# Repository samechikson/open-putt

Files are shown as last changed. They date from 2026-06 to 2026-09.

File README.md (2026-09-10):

# Open Putt

This repo has the code and instructions to build a 3D printed golf putting-analysis tool to measure a player's putting accuracy and speed.

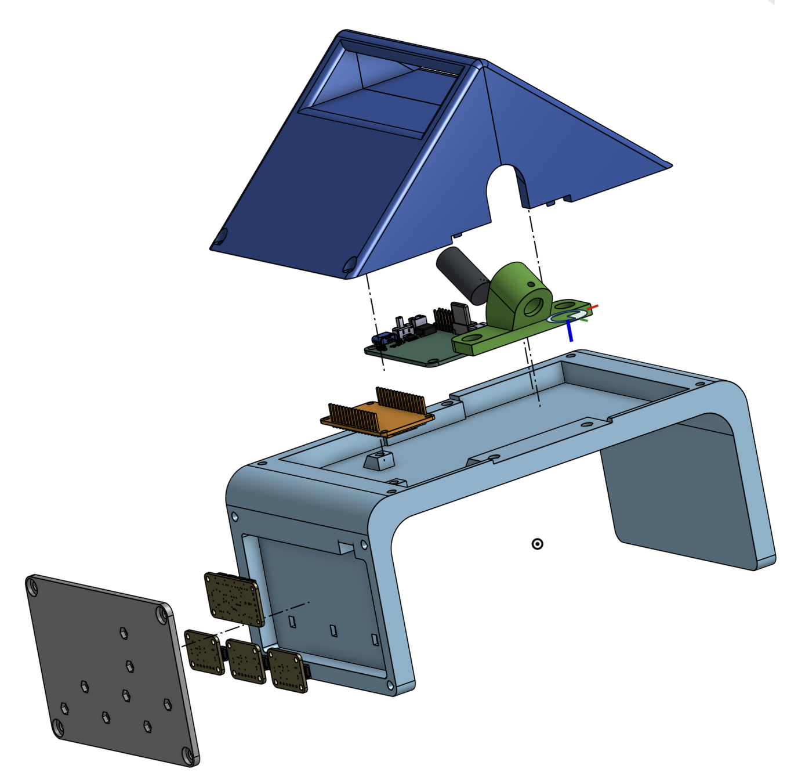
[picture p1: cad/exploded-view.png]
Exploded view of the Open Putt enclosure and components


---

## Repository layout

| Path | What it is |
|---|---|
| `microcontroller/` | ESP32 (Arduino C++) firmware for the physical laser gate + ToF sensors, and its bring-up sketches. |
| `cad/` | Renders and print settings for the 3D-printed enclosure; links to the editable CAD in Onshape. |
| `ios/` | SwiftUI app (`PuttingGate`). Connects to the hardware gate over BLE and writes each putt **directly to Firestore** via the Firebase iOS SDK; shows history/settings. |
| `frontend/` | React 19 + TypeScript + Vite + Tailwind v4 web app for showing history of putting sessions. Reads/writes Firestore **directly** via the Firebase Web SDK (no backend calls). Served by Firebase Hosting. |
| `backend/` (optional) | Python / FastAPI service on Google Cloud Run. Now only the legacy ESP32 direct-post ingest path (`POST /api/device/putts`, Admin SDK). |
| `backend/db/README.md` | The Firestore collection model (data lives in Firestore Native mode). |
| `firestore.rules` / `firestore.indexes.json` | Per-user client access for the web + iOS apps; no composite indexes. |
| `docs/` | Operator runbooks (the Firestore + Firebase-auth migration runbooks). |
| `start.sh` | One command to run the whole web stack locally (with the Firestore emulator). |

---

## Getting started

- **Build a gate and run it end-to-end** — gather parts, print the enclosure, wire
  and flash the electronics, and roll your first putt:
  [`ASSEMBLY.md`](ASSEMBLY.md).
- **Run the software on your own infrastructure** — your Firebase project, the web +
  iOS apps, and the optional backend: [`SETUP.md`](SETUP.md).

Each component has a deeper doc: [`microcontroller/README.md`](microcontroller/README.md)
(hardware wiring, geometry, firmware), [`cad/README.md`](cad/README.md) (the printable
enclosure), [`backend/db/README.md`](backend/db/README.md) (the Firestore data model),
and [`CLAUDE.md`](CLAUDE.md) (architecture and conventions).

---

## Development

### Run the whole web stack locally

```bash
./start.sh
```

Sets `AUTH_DEV_UID=local-dev` (skips Firebase verification, attributes all data to one
dev user). Creates `backend/.venv`, runs uvicorn on `:8000`
(`app.main:application --reload`), and `npm run dev` on `:5173` (Vite proxies `/api` →
`localhost:8000`).

**Local database:** `start.sh` launches the **Firestore emulator** (`localhost:8080`)
and points the backend at it via `FIRESTORE_EMULATOR_HOST`, so persistence works
without touching real Firestore. Needs the Firebase CLI (`npm i -g firebase-tools`)
and a Java runtime; without `firebase` on PATH the script warns and runs without
persistence (the app still runs, nothing persists).

### Frontend only

```bash
cd frontend
npm install
npm run dev      # Vite dev server
npm run build    # tsc -b && vite build → frontend/dist
npm run lint     # oxlint
```

Needs `frontend/.env.local` with the `VITE_FIREBASE_*` values for real auth.

### Backend only

```bash
cd backend
python3 -m venv .venv && .venv/bin/pip install -r requirements.txt
AUTH_DEV_UID=dev FIRESTORE_EMULATOR_HOST=localhost:8080 \
  .venv/bin/uvicorn app.main:application --reload --port 8000
```

There is no automated test suite yet, so **verify changes by exercising the flow** —
post a putt to `/api/device/putts` (or relay one from the gate via iOS) and confirm it
reads back from `/api/sessions/{id}/putts`.

### iOS

Open `ios/PuttingGate.xcodeproj` in Xcode, build & run. Requires the Firebase SPM
package and `GoogleService-Info.plist` in the target. To exercise the gate you need the
physical ESP32 device advertising over BLE.

### Microcontroller

From a sketch folder:

```bash
arduino-cli compile --fqbn esp32:esp32:esp32:PartitionScheme=huge_app --upload -p /dev/cu.usbserial-0001 .
arduino-cli monitor -p /dev/cu.usbserial-0001 -c baudrate=115200
```

---

## Deployment

- **Frontend** auto-deploys to Firebase Hosting on push to `main` touching
  `frontend/**`, `firebase.json`, or the workflow
  (`.github/workflows/deploy-frontend.yml`). Vite bakes the `VITE_*` env into the bundle
  at build time.
- **Firestore rules/indexes** are *not* in that workflow (hosting only). The web app
  depends on `firestore.rules`, so deploy them after any change:
  `firebase deploy --only firestore:rules,firestore:indexes`.
- **Backend** deploys to Cloud Run via `bash backend/deploy/cloud-run.sh` (provisioning;
  `--fast` for a code-only rebuild+redeploy). Container is `backend/Dockerfile`
  (Python 3.13-slim; single uvicorn worker — scale via Cloud Run instances). It also
  provisions a **Firestore Native database** and grants the runtime SA
  `roles/datastore.user`. Secrets: `CORS_ALLOW_ORIGINS`, `DEVICE_INGEST_TOKEN` /
  `DEVICE_INGEST_UID` (the legacy direct-post device auth); no DB secret — Firestore
  uses the runtime SA.

> `main` auto-deploys the frontend — be deliberate about what lands there.

---

## License

Released under the [MIT License](LICENSE).

---

For deeper guidance on conventions and cross-cutting changes, see
[`CLAUDE.md`](CLAUDE.md).

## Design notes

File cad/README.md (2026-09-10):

# CAD

**DISCLAIMER**: These files are a work in progress and may change at any time.

<table>
  <tr>
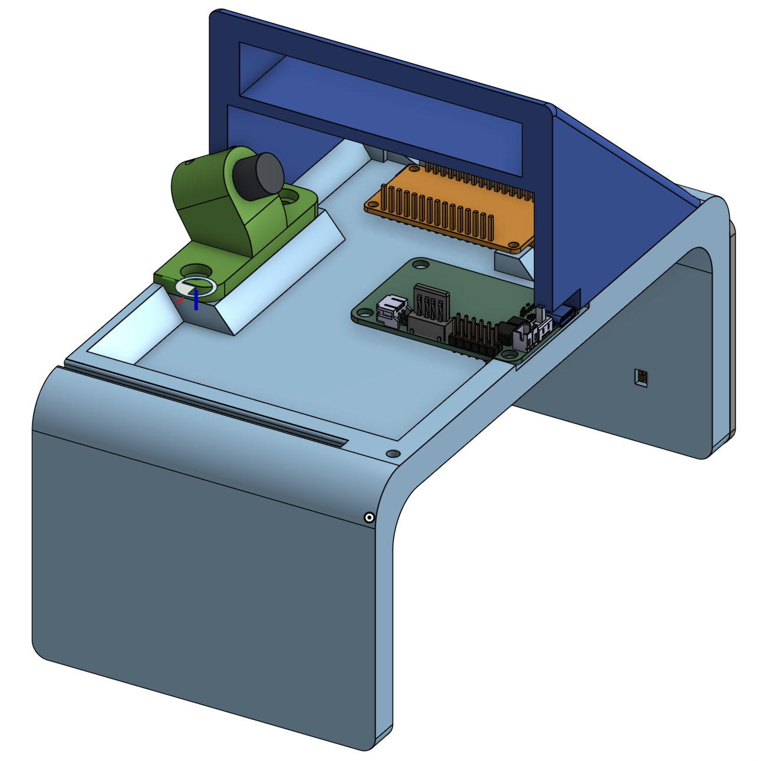
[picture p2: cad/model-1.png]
Rendered CAD model of the Open Putt enclosure
    <td></td>
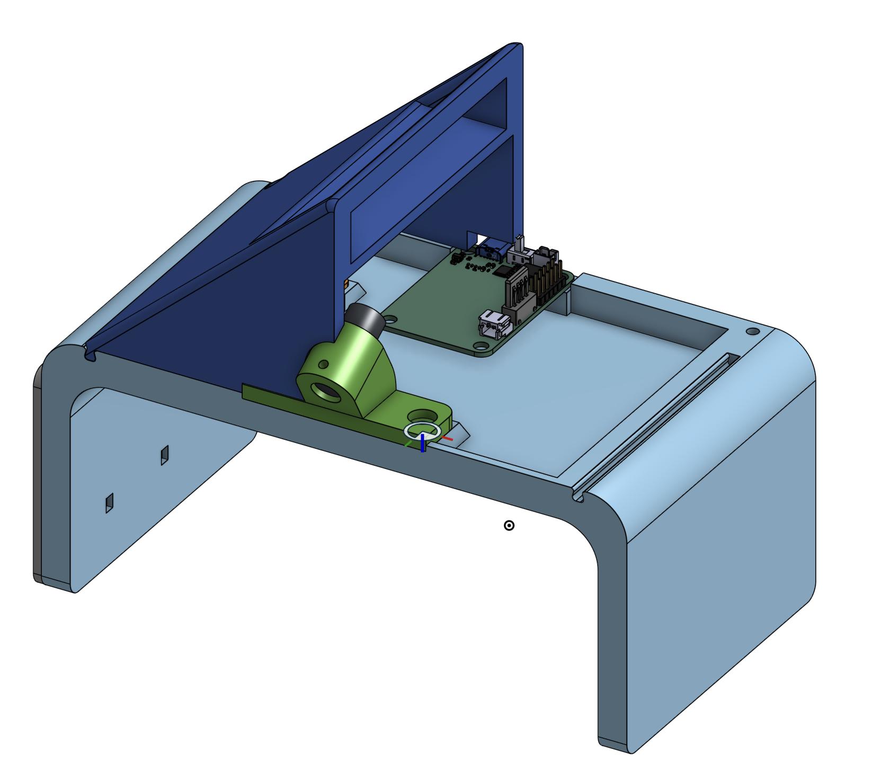
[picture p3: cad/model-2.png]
Rendered CAD model of the Open Putt enclosure
    <td></td>
    
  </tr>
  <tr>
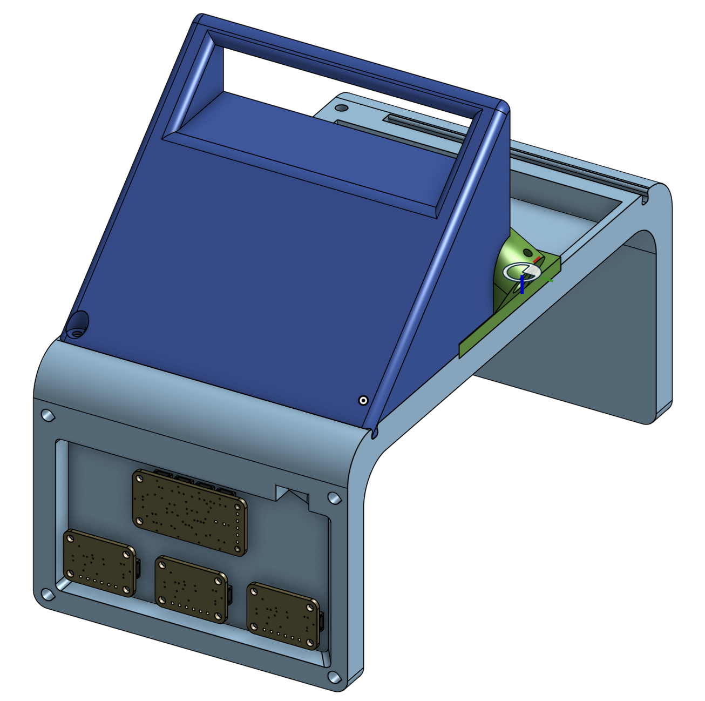
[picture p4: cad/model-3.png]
Rendered CAD model of the Open Putt enclosure
    <td></td>
    <td>Rendered CAD model of the Open Putt enclosure</td>
  </tr>
</table>

CAD for the **Open Putt** enclosure — the 3D-printed "bridge" a golf ball rolls
through. The models live in Onshape (link below); export and print the parts to
build your own gate. The electronics that mount inside are in
[`PARTS_LIST.md`](../PARTS_LIST.md), and the wiring + measurement geometry are in
[`microcontroller/README.md`](../microcontroller/README.md).

## Editable source (Onshape)

The CAD lives in a public Onshape document — open it to view, measure, or remix any
part, then export each part as STL (or STEP) to slice and print:

**<https://cad.onshape.com/documents/c4b592de0452c28abc40e1e5/w/5af483f8f7800af7bf8093f1/e/e14822a6b83e241d4da19292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>**

## Printing

From [`PARTS_LIST.md`](../PARTS_LIST.md):

- A filament 3D printer with at least a **210 × 210 × 200 mm** build volume.
- **PLA or PETG** filament (PETG if the gate will sit in sun/heat).
- **M3 and M4 heat-set threaded inserts** for the mounting bosses.

General guidance (tune per part / printer):

- ~0.2 mm layer height, 3–4 perimeters, 15–20% infill — the gate is structural,
  not cosmetic.
- Print sensor and laser mounts in the orientation that keeps their mating faces
  flat and square, so alignment holds without support scarring.
- Set your slicer's hole/insert diameters to your inserts; heat-set them after
  printing.

## Contributing

Improvements and remixes are welcome. If you change a mount that affects sensor or
laser geometry, note it in your PR so the calibration/measurement docs can be kept
honest — see [`microcontroller/README.md`](../microcontroller/README.md) for the
geometry the firmware assumes.

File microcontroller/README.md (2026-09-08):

# Putt Offline Detector

A device that a golf ball rolls through (a 3D-printed "bridge" gate) which measures
how far **offline** each putt is from the center line, reporting it as **PUSH**
(ball past center) or **PULL** (ball short of center) in millimeters. Built first on
a Raspberry Pi, then migrated to an ESP32 for portability.

---

## Current status

- ✅ **Laser** on at startup
- ✅ **3× VL53L4CD** distance sensors read through an I2C multiplexer
- ✅ **Putt detection + push/pull offset** working standalone on the ESP32 (verified:
  a real putt reported a consistent ~+43 mm PUSH across all three sensors)
- ✅ **Per-sensor speed + center calibration** (per-sensor `CENTER_READING`, jig-measured)
- ✅ **BLE to the phone** — each putt is sent over BLE to the iOS app, which relays it to
  the backend under the signed-in user (no WiFi/hotspot on the ESP32). See "Transport".

---

## Hardware

### Final build (ESP32)

| Part | Notes |
| --- | --- |
| **ELEGOO ESP32 DevKit** (ESP32-WROOM-32, USB-C, CP2102) | Classic dual-core, WiFi + BT/BLE 4.2. 2.4 GHz WiFi only. |
| **3× Adafruit VL53L4CD** ToF distance sensors (~1–1300 mm) | All share I2C address `0x29`. |
| **Adafruit PCA9548** I2C multiplexer (TCA9548A-compatible) | Address `0x70`. Isolates the 3 identical sensors — one per channel. |
| **Green laser module** (520 nm, 3–5 V) | Driven directly from a GPIO. Red + / black − leads. |
| STEMMA QT / Qwiic cabling + jumpers, Wago 221 connectors | |
| 10,000 mAh USB power bank | Field power via USB-C. |

Sensors are on mux **channels 0, 7, 4** (Sensor 1, 2, 3), mounted in a row along the
roll direction.

### ESP32 wiring

The PCA9548 mux connects to the ESP32 over a 4-wire STEMMA QT / Qwiic cable, using the
standard Qwiic wire colors:

| Mux wire (STEMMA QT) | Signal | ESP32 pin  |
| --- | --- | --- |
| Red | VIN (3.3 V) | **3V3** |
| Black | GND | **GND** |
| Blue | SDA | **GPIO21** |
| Yellow | SCL | **GPIO22** |

The green laser is wired separately: red + → **GPIO26**, black − → **GND**.

Pin rules learned: avoid input-only **GPIO34–39** for outputs, and avoid strapping
pins (0, 2, 5, 12, 15) for buttons.

---

## The measurement (geometry + math)

- Sensor face → far wall of the gate ≈ **170 mm**; a centered ball's near surface
  reads ~**70–77 mm** depending on the sensor.
- A ToF sensor reads the distance to the ball's **near surface**, not its center.
  A standard golf ball is ⌀**42.67 mm** (radius **21.335 mm**).
- **Per-sensor calibration.** Rather than a shared geometric reference, each sensor
  stores `CENTER_READING[i]` — what it reads for a ball rolled dead-center through
  the gate (measured with a centering jig). The offset is the deviation from that:
  `offset_mm = closest_reading_mm − CENTER_READING[i]`
  - `> 0` → **PUSH**, `< 0` → **PULL**, within a small dead-band → **CENTER**
- This zeroes a center hit and absorbs each sensor's fixed bias — mounting
  differences and the middle sensor's crosstalk offset — in one step, so there's no
  single `CENTER_MM` or ball-radius term to tune. Re-measure `CENTER_READING` if the
  mount changes. Usable range is roughly ±64 mm before the ball touches a wall.

### Detection algorithm

1. **Calibrate** each channel's empty-gate baseline at startup (median of ~20 reads,
   ~170–180 mm).
2. A **ball is present** on a channel when its reading drops ≥ **25 mm** below that
   channel's baseline.
3. Capture the **closest approach** per sensor during the pass — the lowest of the
   *middle* samples (the first/last are the ball caught off-axis at the edge of the
   ~18° cone, so they read long and are dropped) = its true lateral distance.
4. **Finalize** once the gate has been clear for 150 ms; compute per-sensor offset +
   an average, print PUSH/PULL.

Tuning knobs live as constants at the top of the sketch: `CENTER_READING[]`
(per-sensor center calibration), `DETECT_MARGIN_MM`, `DEAD_BAND_MM`,
`CLEAR_TIMEOUT_MS`, `SENSOR_SPACING_MM` (for speed), `INVERT_PUSH_PULL` (flip if
push/pull come out mirrored for your sensor side).

---

## Code

### ESP32 (Arduino C++) — current platform

- `putt_tracker/putt_tracker.ino` — **the main program**: laser on, calibrate,
  detect putts, report push/pull.
- `sensors/sensors.ino` — reads all 3 sensors (bring-up/debug).
- `laser/laser.ino` — blinks the laser (GPIO26 bring-up).
- `blink/blink.ino` — onboard-LED blink (toolchain smoke test).

---

## Toolchain (macOS, ESP32)

Uses `arduino-cli` (installed via Homebrew).

- ESP32 core: `esp32:esp32` **3.3.11**
- Library: **STM32duino VL53L4CD** 1.0.5 (`arduino-cli lib install "STM32duino VL53L4CD"`)
- Board FQBN: `esp32:esp32:esp32:PartitionScheme=huge_app` (the `huge_app` partition is
  required — BLE overflows the default 1.3 MB app partition)
- Serial port (this Mac): `/dev/cu.usbserial-0001`

```bash
# compile + upload (from a sketch folder)
arduino-cli compile --fqbn esp32:esp32:esp32:PartitionScheme=huge_app --upload -p /dev/cu.usbserial-0001 .

# watch serial output (Ctrl-C to quit)
arduino-cli monitor -p /dev/cu.usbserial-0001 -c baudrate=115200
```

---

## Transport (BLE → phone → backend)

The ESP32 has **no WiFi**. It advertises over BLE as **`PuttingGate`** and sends each
finalized putt as a notification; the iOS app (a BLE central) receives it and relays it
to `POST /api/device/putts` under the signed-in user's Firebase login. This means no
hotspot, no WiFi credentials, and putts are attributed to the real user.

- Service UUID `6b1a0001-8c2f-4d3a-9e5b-1f2c3d4e5f60`, notify characteristic
  `6b1a0002-…` — these must match the iOS app (`GateConnection.swift`).
- Payload (UTF-8 JSON, fits one BLE notification):
  `{ "session_id", "putt_index", "offset_mm", "label", "speed_mps", "sensors": [...] }`.
- The laser flashes only when a phone is connected and received the notification.
- **BLE needs the bigger app partition** — build with
  `--fqbn esp32:esp32:esp32:PartitionScheme=huge_app` (BLE overflows the default).

### Next steps

- **Later / optional:** a physical on/off (latching button on the `EN` pin); a
  transistor to drive the laser cleanly; deep-sleep + button wake; a BLE write
  characteristic so the phone can confirm a *backend*-accepted putt (flash on 201).

---

## Gotchas & lessons (hard-won)

- **Each identical-address sensor needs its own mux channel** — that's the whole reason
  for the PCA9548.
- **ESP32 serial quirks:** the boot-ROM prints at **74880 baud** (looks like garbage at
  115200 — ignore it), and the board **auto-resets when the serial port is opened**, which
  makes scripted/headless serial capture flaky. Use `arduino-cli monitor` interactively.
- **Per-sensor center calibration beats a shared geometric model** — the sensors differ
  enough (mounting + optical crosstalk on the middle one) that a single `CENTER_MM` left
  a consistent multi-mm bias. Zeroing each sensor against a dead-center ball fixes it.

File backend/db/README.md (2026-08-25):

# Firestore data model

Persistence is **Firestore (Native mode)**, accessed two ways:

- The **web and iOS apps** connect directly with the Firebase SDK, so
  `firestore.rules` is the enforcement boundary: a signed-in user may only touch
  (and create) docs whose `user_id` is their uid. iOS relays hardware-gate putts,
  so it *creates* sessions/putts on ingest and keeps `putt_count` in sync; both
  apps read, edit session metadata, and delete their own.
- The **backend** (`backend/app/db.py`) connects with the Admin SDK
  (service-account credentials on Cloud Run; the Firestore **emulator** locally),
  which **bypasses** security rules. It's now used only by the legacy ESP32
  direct-post ingest path. Ownership is enforced in application code by the same
  `user_id` field.

There is no schema/migration file: Firestore is schemaless, and this project
migrated off Postgres (the old `supabase/migrations/` + `db/schema.sql` are gone;
existing data was disposable test data). See `docs/migration-firestore.md`.

## Collections

### `putters/{putterId}`
`putterId` is a uuid4 generated on create. One doc per user-owned club.

| field | notes |
|---|---|
| `user_id` | Firebase UID (owner) |
| `name` | required |
| `brand`, `model`, `length_in`, `lie_deg`, `grip` | optional spec |
| `is_active` | at most one `true` per user (enforced in `set_active_putter`) |
| `created_at` | server timestamp |

### `sessions/{sessionId}`
`sessionId` is the iOS session UUID — the idempotent upsert key. One doc per
hardware-gate session; it's created (already complete) on the session's first
relayed putt and gains putts as the player putts.

Fields: `user_id`, `created_at` (server ts), `length_feet`, `break_type`,
`putt_count` (denormalized), and `putter_id` (nulled when the putter is deleted).
`length_feet` / `break_type` / `putter_id` are set via `PATCH /sessions/{id}`.

### `putts/{sessionId_index}`
A **top-level** collection (not a subcollection). The doc id is
`"{session_id}_{putt_index}"`, which makes the hardware gate's per-(session,
index) upsert naturally idempotent. Each doc denormalizes `session_id` and
`user_id` from its session so putts can be queried and ownership-checked without
a join.

Fields: `session_id`, `user_id`, `putt_index`, `offset_mm`, `direction`,
`speed_mps` (null when the ball tripped only one sensor), and `sensor_offsets_mm`
(the per-sensor offsets behind the average).

## Query strategy (no composite indexes)

Every query filters on a **single** field (equality) and does any remaining
ordering / secondary filtering in Python — session and putt counts per user are
small. That's why `firestore.indexes.json` is empty: Firestore auto-creates the
single-field indexes these queries need.

**If you change a returned field set, update it in all three places:** `db.py`'s
`_*_FIELDS`, and the frontend TS types (`sessions.ts` / `putters.ts` /
`analysis.ts`).

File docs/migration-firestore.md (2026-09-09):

# Migration: Postgres (Supabase) → Firestore

This runbook records the move of the Open Putt backend's **persistence layer**
off Supabase Postgres onto **Firestore (Native mode)**. Firebase Auth was already
in place (see `migration-firebase-auth.md`); this change only swaps the database.
Existing data was disposable test data and was **not** migrated — the Postgres
database can be torn down.

> **Follow-up (video pipeline removed).** Shortly after this migration, the
> deprecated **video / OpenCV upload path was removed entirely** — putts are now
> ingested only from the hardware gate (relayed by the iOS app to
> `POST /api/device/putts`). See the [dedicated section below](#follow-up-removing-the-video-pipeline)
> for exactly what that deleted. The Firestore field lists in this document
> describe the *interim* shape; the current gate-only shape is in
> `backend/db/README.md`.

## What changed

- **`backend/app/db.py`** — rewritten on the Firestore Admin SDK
  (`google-cloud-firestore`). Every public function keeps its **exact signature
  and return shape**, so `main.py`, the frontend, and iOS are unchanged.
- **Data model** — three collections (`putters`, `sessions`, top-level `putts`);
  see `backend/db/README.md`. Ownership is a `user_id` field on every doc, checked
  in application code (the Admin SDK bypasses security rules).
- **`requirements.txt`** — dropped `psycopg[binary,pool]`, added an explicit
  `google-cloud-firestore` (also pulled in transitively by `firebase-admin`).
- **`start.sh`** — runs the **Firestore emulator** locally instead of Postgres.
- **`firebase.json` / `firestore.rules` / `firestore.indexes.json`** — added
  Firestore config: deny-all client rules, no composite indexes, emulator on
  `:8080`.
- **`backend/deploy/cloud-run.sh`** — enables `firestore.googleapis.com`, creates
  the Native database, grants the runtime SA `roles/datastore.user`, and drops the
  `DATABASE_URL` secret.
- **Removed** — `supabase/migrations/`, `backend/db/schema.sql`, and every
  `DATABASE_URL` / `psycopg` reference.

## Config differences

| | Postgres (before) | Firestore (after) |
|---|---|---|
| Client | `psycopg` pool from `DATABASE_URL` | Firestore Admin SDK (ADC + project id) |
| Prod auth to DB | `DATABASE_URL` secret | runtime SA + `roles/datastore.user` |
| Prod project id | — | `GOOGLE_CLOUD_PROJECT` (auto on Cloud Run) / `FIREBASE_PROJECT_ID` |
| Local dev | local Postgres | Firestore emulator (`FIRESTORE_EMULATOR_HOST`) |
| Schema | `db/schema.sql` + migrations | schemaless; model in `db/README.md` |

`db.py` is **fail-soft**: with no project id and no emulator host it no-ops, so
analysis still runs locally without persistence.

## Local development

1. Install the Firebase CLI and a Java runtime:
   ```bash
   npm i -g firebase-tools
   # Java: e.g. `brew install openjdk` on macOS
   ```
2. Run the stack — `start.sh` boots the emulator and wires it up automatically:
   ```bash
   ./start.sh
   ```
   The emulator listens on `localhost:8080`; the backend picks it up via
   `FIRESTORE_EMULATOR_HOST`. Emulator data is in-memory (wiped on stop).

## Deploying to production

`bash backend/deploy/cloud-run.sh` now provisions Firestore end to end:

- enables `firestore.googleapis.com`;
- `gcloud firestore databases create --location=<region> --type=firestore-native`
  (one-time; the location is **permanent**);
- grants `roles/datastore.user` to the runtime service account;
- deploys with `FIREBASE_PROJECT_ID` / `GCP_PROJECT` set (Cloud Run also injects
  `GOOGLE_CLOUD_PROJECT`), and **no** `DATABASE_URL` secret.

A code-only redeploy is still `bash backend/deploy/cloud-run.sh --fast`.

## Notes / gotchas

- **No composite indexes.** Queries filter a single field and sort/filter the rest
  in Python (`db.py`). If you ever add a query with two field constraints or a
  server-side `order_by` on a different field, Firestore will demand a composite
  index — add it to `firestore.indexes.json` and `firebase deploy --only
  firestore:indexes`, or prefer the single-field + Python pattern.
- **Deletes cascade in code.** Firestore has no `ON DELETE CASCADE`; deleting a
  session removes its putts via `_delete_putts_for_session`.
- **`putt_count`** is recomputed by counting putt docs after each ingest/delete.
- **Timestamps.** `created_at` is a server timestamp; reads convert it to ISO-8601,
  matching the old Postgres→FastAPI JSON shape, so the frontend needs no change.

## Follow-up: removing the video pipeline

The video / OpenCV upload path was **deprecated and then removed** — a player never
uploads a clip; every putt is measured by the hardware gate and relayed by the iOS
app to `POST /api/device/putts`. Sessions are now gate-only. What was deleted:

- **Backend code** — `analyzer.py` (the OpenCV pipeline), `segmenter.py` (motion
  helpers), `cloud.py` (Cloud Storage + Cloud Tasks helpers), and `backend/scripts/`
  (CV debugging scripts). `main.py` lost every video endpoint (`/analyze`,
  `/uploads`, `/analyze-session`, `/process`, `/sessions/{id}/reanalyze`,
  `/sessions/{id}/video`, `/sessions/{id}/putts/{i}/frame`, `/detect-ball`,
  `/calibration-check`, `/local-storage/*`) and `db.py` lost the video write path
  (`persist_session`, `create_pending_session`, `set_session_status`,
  `begin_reanalysis`, `get_session_video_path`, `get_putt_crossing_frame`).
- **Dependencies** — `opencv-contrib-python-headless`, `numpy`,
  `google-cloud-storage`, `google-cloud-tasks`, and `python-multipart` dropped from
  `requirements.txt`; `ffmpeg` dropped from the `Dockerfile`.
- **Data model slimmed** — sessions kept `created_at`, `length_feet`, `break_type`,
  `putt_count`, `putter_id` (dropped `captured_at`, `file_name`, `video_path`,
  `status`/`error`, `fps`/`frame_count`/`duration_s`/`segments_detected`, and the
  `cal_*` block). Putts kept `putt_index`, `offset_mm`, `direction`, `speed_mps`,
  `sensor_offsets_mm` (dropped `start_s`/`end_s`, `track_count`, `crossing_frame`,
  and the raw pixel fields). See `backend/db/README.md` for the current shape.
- **Infra** — `cloud-run.sh` no longer provisions the GCS bucket, Cloud Tasks
  queue, lifecycle rules, signer-SA IAM, or the `TASKS_INTERNAL_TOKEN` secret
  (existing cloud resources aren't torn down by the script — delete those by hand).
- **Frontend** — deleted `AnalyzeView`, `SessionUploader`, `VideoCard`; the web app
  is now a read/review surface (no upload/analyze/video-playback UI).
- **iOS** — `SessionRow` dropped the `status` / `captured_at` fields it decoded.

If you need the old video code, it's in the git history prior to this change.

## Follow-up: clients moved onto the Firebase SDK

After the above, both apps were taken **off the backend API** and onto the Firebase
SDK, talking to Firestore directly (scoped by `firestore.rules`). The backend now
only serves the legacy ESP32 direct-post ingest path.

- **`firestore.rules`** — went from deny-all → per-user: a signed-in user may
  read/write (and, for the iOS ingest, *create*) docs whose `user_id` is their uid.
  Rules changes take effect only on `firebase deploy --only firestore:rules` — the
  hosting workflow does **not** deploy them.
- **Web app** — `sessions.ts` / `putters.ts` rewritten on the Web SDK; `api.ts`
  (the Bearer-token fetch wrapper) deleted. The web app makes no backend calls.
- **iOS app** — added the `FirebaseFirestore` SPM product (wired by hand in
  `project.pbxproj`, mirroring `FirebaseAuth`). `SessionMetadataService` became the
  Firestore data layer (reads + `apply` + `deletePutt` + **`ingest`**); the ingest
  ports the old backend logic — session upsert, the `offset_mm` / per-sensor
  **sign-inversion**, and the recomputed `putt_count`. `GatePuttRelay` and
  `AppSettings` (backend URLs) were deleted; the model structs
  (`SessionRow` / `SessionPutt` / `Putter`) now build from `DocumentSnapshot`.

**Verifying the iOS build:** the `project.pbxproj` package edit can't be compiled
outside Xcode — open the project, let SPM resolve `firebase-ios-sdk`, and build. If
resolution fails, remove/re-add the `FirebaseFirestore` product via the target's
**Frameworks, Libraries, and Embedded Content** and rebuild.

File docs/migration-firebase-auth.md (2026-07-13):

# Migration runbook: Supabase Auth → Firebase Auth (data stays on Supabase)

Operator runbook for moving **authentication** to Firebase while keeping the
**database on Supabase Postgres**, and routing all data access through the
backend (the browser and iOS no longer hit Supabase directly).

The application code is already migrated on branch `migrate-supabase-to-firebase`.
The backend now connects straight to Supabase's Postgres with `psycopg` (via the
connection pooler) as the service role, verifies Firebase ID tokens, and enforces
ownership per-user. The steps below are the infra + data work in your
GCP/Firebase/Supabase accounts, ending in an atomic cutover.

> ⚠️ **Do not merge the branch to `main` until steps 1–5 are done and the
> `VITE_FIREBASE_*` repo variables are set.** CI auto-deploys the frontend on
> push, and it needs the Firebase config + a Firebase-auth backend, or the live
> site breaks.

Project: `putting-gate` (Firebase + Cloud Run). Region `us-central1`.

**No Cloud SQL, no data-table migration** — the sessions/putts/putters rows stay
in Supabase. Only the schema is nudged (migration 0004) and users are recreated
in Firebase.

---

## 1. Enable Firebase Auth + register apps

In the [Firebase console](https://console.firebase.google.com/project/putting-gate):
1. **Authentication → Sign-in method → Email/Password → Enable.**
2. **Project settings → Your apps → Add app → Web.** Copy the config values
   (`apiKey`, `authDomain`, `projectId`, `appId`, `storageBucket`,
   `messagingSenderId`).
3. **Add app → iOS**, bundle id matching the Xcode target. Download
   `GoogleService-Info.plist`.

## 2. Migrate the Supabase schema (0004) — ⚠️ AT CUTOVER ONLY

`supabase/migrations/0004_firebase_auth.sql` drops the client RLS policies + the
`set_active_putter` function, drops the `auth.users` FKs, and widens `user_id`
from `uuid` to `text` (Firebase UIDs). Existing UUID values cast cleanly and stay
valid.

> **Do not run this until the cutover (step 7).** Dropping the RLS policies breaks
> the *currently-deployed* app, which still reads Supabase directly under RLS.
> The new backend connects as the service role (bypassing RLS) and *requires*
> `user_id` to be `text`, so 0004 and the new backend/frontend must go live
> together. It's listed here for reference; apply it in step 7.

Run it via the Supabase SQL editor, or `supabase db push`, or:
```bash
psql "$SUPABASE_DB_URL" -v ON_ERROR_STOP=1 -f supabase/migrations/0004_firebase_auth.sql
```

## 3. Point the backend at Supabase Postgres (DATABASE_URL)

In the Supabase dashboard: **Project settings → Database → Connection pooling** →
copy the pooler connection string. Use the **Transaction** pooler (IPv4, works
from Cloud Run) and append `?sslmode=require`:

```
DATABASE_URL=postgresql://postgres.<ref>:<db-password>@aws-0-<region>.pooler.supabase.com:6543/postgres?sslmode=require
```

Put it in `backend/.env` (read by the deploy script), replacing the old
`SUPABASE_*` entries. The code already disables prepared statements
(`prepare_threshold=None`) for pooler compatibility. `cloud-run.sh` seeds this as
the `DATABASE_URL` secret and sets `FIREBASE_PROJECT_ID` for token verification.

## 4. Set the frontend Firebase config as GitHub repo variables

Public values (shipped in the bundle); the deploy workflow injects them.

```bash
R=samechikson/putting-gate-app
gh variable set VITE_FIREBASE_API_KEY             --repo $R --body "<apiKey>"
gh variable set VITE_FIREBASE_AUTH_DOMAIN         --repo $R --body "putting-gate.firebaseapp.com"
gh variable set VITE_FIREBASE_PROJECT_ID          --repo $R --body "putting-gate"
gh variable set VITE_FIREBASE_APP_ID              --repo $R --body "<appId>"
gh variable set VITE_FIREBASE_STORAGE_BUCKET      --repo $R --body "<storageBucket>"
gh variable set VITE_FIREBASE_MESSAGING_SENDER_ID --repo $R --body "<messagingSenderId>"
# Optional: remove the now-unused Supabase vars.
gh variable delete VITE_SUPABASE_URL --repo $R; gh variable delete VITE_SUPABASE_ANON_KEY --repo $R
```

Also fill the same values into `frontend/.env.local` for local dev.

## 5. Migrate users → Firebase (preserve UID, password reset)

Export users from Supabase (SQL editor):
```sql
select id, email from auth.users where email is not null;
```

Import into Firebase **preserving each UID** (so existing `user_id` values still
match) with **no password** — users reset via email:
```json
{ "users": [ { "localId": "<supabase-uuid>", "email": "<email>", "emailVerified": true } ] }
```
```bash
firebase auth:import users.json --project putting-gate
# Then send each user a reset link (console → Authentication, or Admin SDK
# generatePasswordResetLink / sendPasswordResetEmail).
```

## 6. iOS: add the Firebase SDK

In Xcode (Swift changes already in the branch):
1. **File → Add Package Dependencies →** `https://github.com/firebase/firebase-ios-sdk`
   → add **FirebaseAuth** to the app target.
2. Add `GoogleService-Info.plist` (step 1) to the app target.
3. Build & run; confirm sign-in, upload, and that the session appears on web.

## 7. Cutover

Do these back-to-back (a few minutes of downtime for the old app is expected —
steps 1–2 break it, step 3 restores it on the new version):

1. **Apply migration 0004** (step 2) to Supabase.
2. **Deploy the backend:** `bash backend/deploy/cloud-run.sh` (seeds the
   DATABASE_URL secret, sets FIREBASE_PROJECT_ID, builds, deploys, sets
   `PROCESS_URL=.../api/process`).
3. **Merge** `migrate-supabase-to-firebase` → `main`. CI builds the frontend with
   the Firebase repo vars and deploys to Hosting.
4. **Verify** (checklist below).
5. In Supabase, you can now disable the Auth provider / stop relying on the anon
   key (the app no longer uses either). The Postgres database stays.

Everything in steps 1, 3, 4, 5, and 6 is safe to do **ahead of time** (they don't
touch the live app): registering the Firebase apps, grabbing DATABASE_URL,
setting repo vars, importing users to Firebase, and adding the iOS SDK.

## 8. Verification checklist

- `curl https://putting-gate.web.app/api/health` → `{"status":"ok"}`.
- Unauthenticated `curl …/api/sessions` → **401**.
- Web: sign up a new user → sign out → sign in. A migrated user resets password
  and sees their historical sessions/putters.
- Ownership: a user cannot read another user's sessions/putters.
- Upload a clip → status polls `queued → processing → done`; video plays back.
- Putters: add/edit/delete; activating one leaves exactly one active.
- iOS: sign in, upload, session shows on web under the same account.

## Rollback

Until you disable Supabase Auth (step 7.4), rollback is: revert the `main` merge
(CI redeploys the old frontend) and redeploy the previous backend revision
(`gcloud run services update-traffic putting-gate-backend --to-revisions=<prev>=100`).
Keep the cutover window short so little new data is written under the new UIDs.

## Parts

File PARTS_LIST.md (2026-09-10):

# Parts List

Physical parts needed to build the **Open Putt** — the 3D-printed "bridge"
gate a golf ball rolls through, which measures how far offline each putt crosses
(PUSH/PULL in mm) and its speed, then sends each putt over BLE to the iOS app.

Wiring, geometry, and the measurement math live in
[`microcontroller/README.md`](microcontroller/README.md).

## Electronics

| # | Part | Qty | Price (approx, ea) | Notes |
| --- | --- | --- | --- | --- |
| 1 | **[ELEGOO ESP32 DevKit](https://www.amazon.com/ELEGOO-ESP-WROOM-32-Development-Bluetooth-Microcontroller/dp/B0D8T53CQ5)** (ESP32-WROOM-32, USB-C, CP2102) | 1 | ~$10 | Classic dual-core, WiFi + BT/BLE 4.2 — the gate uses **BLE only** (no WiFi). This could be any bluetooth enabled ESP32. |
| 2 | **[Adafruit VL53L4CD](https://www.adafruit.com/product/5396)** ToF distance sensor (~1–1300 mm) | 3 | ~$15 | Measure the ball's near surface as it passes. All three share I²C address `0x29`, which is why the mux is required. Mounted in a row along the roll direction. |
| 3 | **[Adafruit PCA9548](https://www.adafruit.com/product/5626)** I²C multiplexer (TCA9548A-compatible) | 1 | ~$7 | Address `0x70`. Gives each identical-address sensor its own channel. Sensors sit on channels **0, 7, 4** (Sensor 1, 2, 3). |
| 4 | **[apinex TZ12X20-520L green laser module](https://www.apinex.com/ret2/TZ12X20-520L.html)** (520 nm, 3–5 V) | 1 | ~$50 | Defines the center line of the gate. Driven directly from a GPIO. |
| 5 | **[PM11 battery module](https://github.com/nulllaborg/pm11-module)** | 1 | ~$10 | Field power to the ESP32 over USB-C. Sold as a pack. |

Electronics subtotal: **~$122** (VL53L4CD ×3 = ~$45).

## Wiring & connectors

| # | Part | Price (approx) | Notes |
| --- | --- | --- | --- |
| 6 | STEMMA QT / Qwiic cables | ~$4 | Chain the VL53L4CD sensors and PCA9548 mux (both are STEMMA QT boards). |
| 7 | Jumper wires (M–M / M–F) | ~$5 | Laser, power, and I²C tie-ins to the ESP32 header pins. |
| 8 | USB-C cable | ~$5 | ESP32 ↔ power bank (and ESP32 ↔ Mac for flashing/serial). |

## Fasteners & mounting

| # | Part | Price (approx) | Notes |
| --- | --- | --- | --- |
| 9 | M3 & M4 heat-set threaded inserts + matching screws | ~$13 | Heat-set into the printed bosses to mount the **ESP32** (M3) and the **battery module** (M4). |
| 10  | **[Adafruit M2.5 nylon screw & standoff set](https://www.adafruit.com/product/3299)** | ~$5 | Mount the Adafruit boards (the **VL53L4CD** sensors and the **PCA9548** mux). |

## Connections (ESP32 pinout)

| From | To (ESP32) |
| --- | --- |
| Laser red (+) | **GPIO26** |
| Laser black (−) | **GND** |
| Mux SDA | **GPIO21** |
| Mux SCL | **GPIO22** |
| Mux VIN | **3V3** |
| Mux GND | **GND** |

Pin notes: avoid input-only **GPIO34–39** for outputs, and avoid strapping pins
(0, 2, 5, 12, 15).

## 3D Printing

- A filament 3D printer with at least 210x210x200mm in printable surface area
- PLA/PETG filament
- 3mm and 4mm heat thread inserts

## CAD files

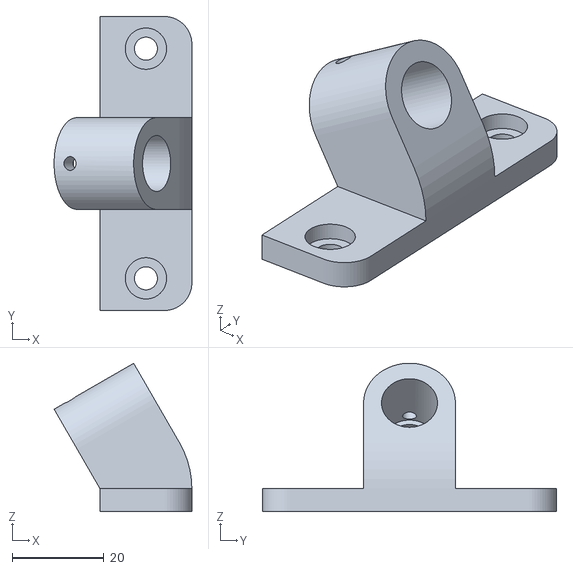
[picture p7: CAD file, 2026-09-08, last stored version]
cad/stl/Putting Gate - Mount.stl
30.0 x 64.0 x 32.3

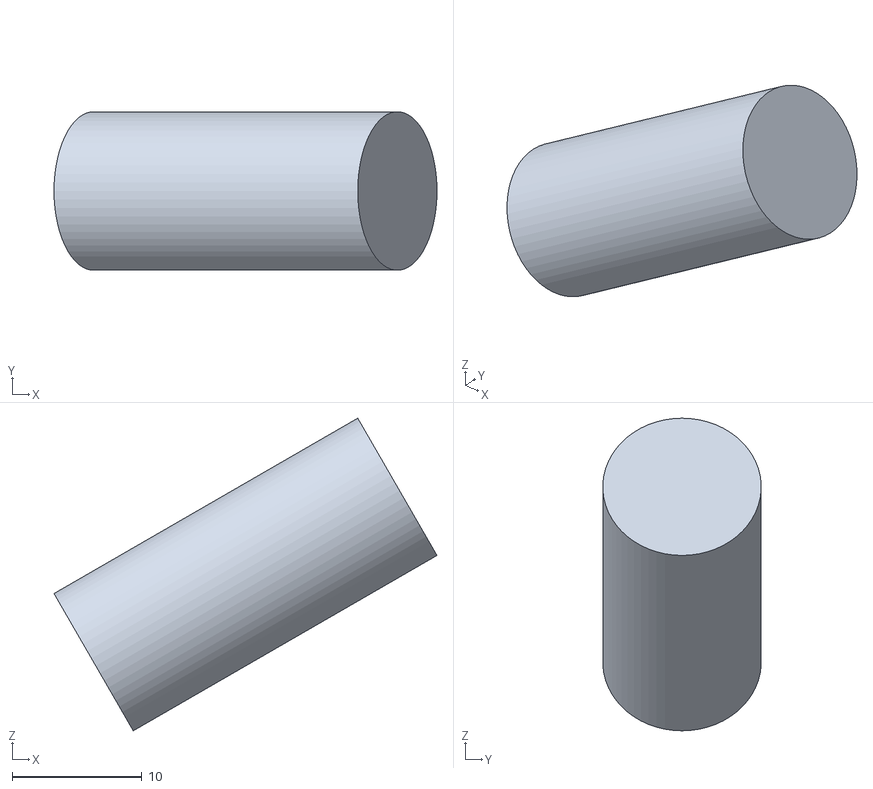
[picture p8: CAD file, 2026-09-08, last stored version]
cad/stl/Putting Gate - Laser.stl
29.5 x 12.2 x 24.1

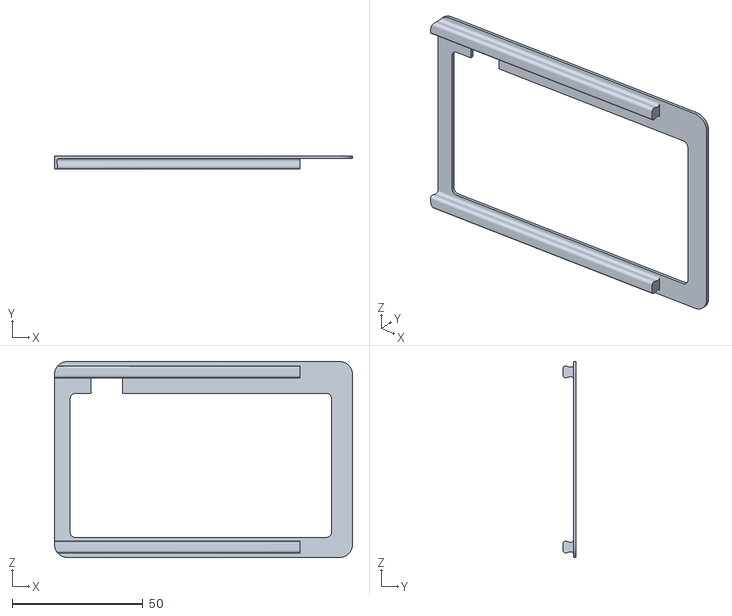
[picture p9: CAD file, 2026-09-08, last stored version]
cad/stl/Putting Gate - Side Cover.stl
114.0 x 5.00 x 75.0

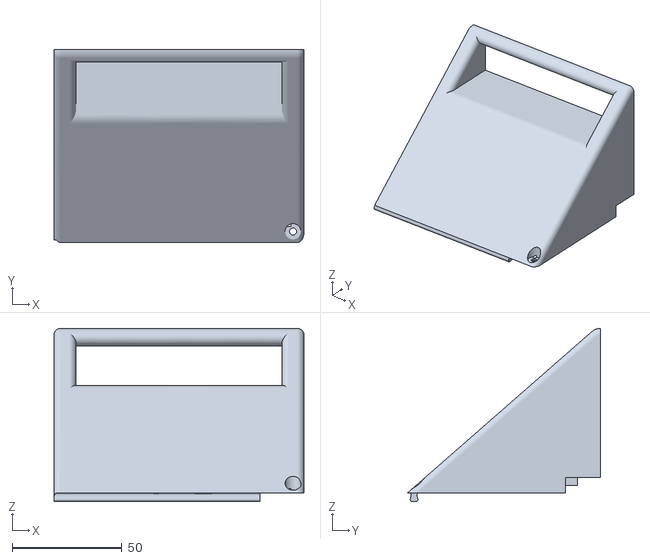
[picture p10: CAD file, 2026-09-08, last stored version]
cad/stl/Putting Gate - Top Cover Right.stl
114.0 x 88.0 x 79.0

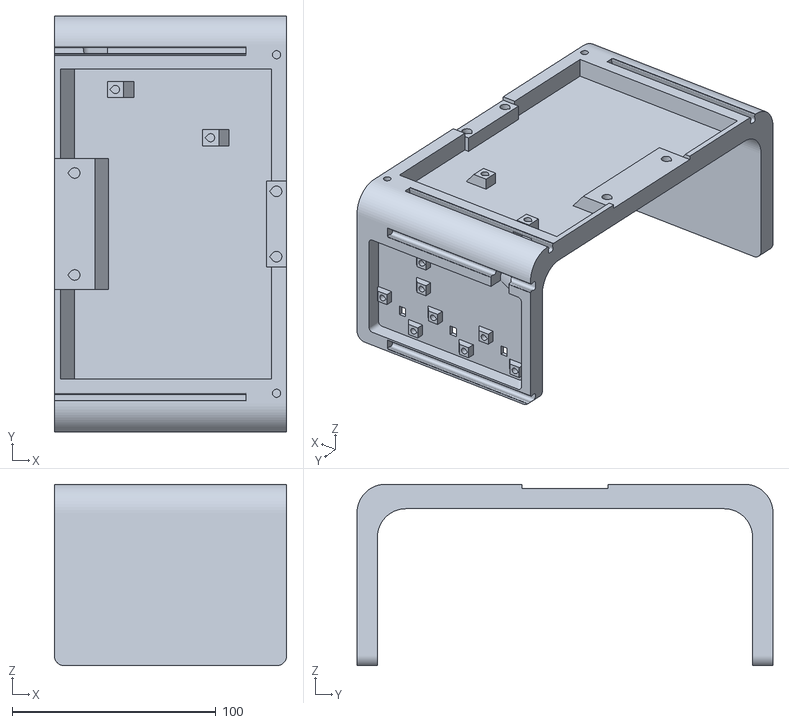
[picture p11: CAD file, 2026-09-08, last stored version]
cad/stl/Putting Gate - gate.stl
114.0 x 204.0 x 89.0

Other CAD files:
cad/stl/Putting Gate - Top Cover Left.stl

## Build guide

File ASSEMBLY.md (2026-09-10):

# Assembly & Getting Started

How to build an Open Putt from scratch and roll your first measured putt. It ties
together the parts list, the printable enclosure, the firmware, and the apps — each
of which has its own deeper doc, linked as you go.

**Roughly what's involved:** gather the parts → print the enclosure → mount and wire
the electronics → flash the ESP32 → set up Firebase and the app → calibrate → putt.
Plan on an afternoon, plus print time.

---

## 1. Gather the parts

See [`PARTS_LIST.md`](PARTS_LIST.md) for the full bill of materials with links and
approximate prices (~$122 in electronics). In short you need: an **ESP32 DevKit**,
**3× Adafruit VL53L4CD** ToF sensors, an **Adafruit PCA9548** I²C mux, a **green
laser module**, a USB-C power bank, STEMMA QT / Qwiic cables, jumper wires, and
**M3 + M4 heat-set inserts**.

## 2. Print the enclosure

The models live in Onshape; see [`cad/README.md`](cad/README.md) for the link and
print settings. You'll need a printer with at least a **210 × 210 × 200 mm** build
volume, **PLA or PETG**.

## 3. Mount the electronics

Press the heat set inserts to the top of the print (3mm for the esp32 and top cover, 4mm for the battery module)

Fit the boards and laser into their printed mounts:

- The **3 ToF sensors** sit on the side panel in a row along the roll direction. The are screwed in using the nylon screws and nuts
- The **PCA9548 mux** and **ESP32** go in the electronics mount/tray.
- The **laser** goes in its holder, aimed down the gate's center line. Add a 3mm screw to tighten it in place.

## 4. Wire it up

Chain the sensors to the mux with STEMMA QT / Qwiic cables (each sensor on its own
channel — **0, 7, 4** for Sensor 1, 2, 3, since all three share I²C address `0x29`),
then wire the mux and laser to the ESP32:

| From | Signal | ESP32 pin  |
| --- | --- | --- |
| Mux — Red | VIN (3.3 V) | **3V3** |
| Mux — Black | GND | **GND** |
| Mux — Blue | SDA | **GPIO21** |
| Mux — Yellow | SCL | **GPIO22** |
| Laser red (+) | — | **GPIO26** |
| Laser black (−) | — | **GND** |

Full wiring, pin rules, and the measurement geometry are in
[`microcontroller/README.md`](microcontroller/README.md).

## 5. Flash the firmware

Install [`arduino-cli`](https://arduino.github.io/arduino-cli/) with the ESP32 core
and the **STM32duino VL53L4CD** library, then flash the main program from
`microcontroller/putt_tracker/`. The **`huge_app` partition scheme is required** —
BLE overflows the default partition:

```bash
cd microcontroller/putt_tracker
arduino-cli compile --fqbn esp32:esp32:esp32:PartitionScheme=huge_app --upload -p /dev/cu.usbserial-0001 .
arduino-cli monitor -p /dev/cu.usbserial-0001 -c baudrate=115200
```

(Adjust the serial port for your machine.) On boot the laser should light and the
serial monitor should show the sensors calibrating their empty-gate baseline. The
`sensors/`, `laser/`, and `blink/` sketches are there for bring-up if a step
misbehaves. See [`microcontroller/README.md`](microcontroller/README.md) for the
toolchain versions and gotchas.

## 6. Calibrate center

The gate zeroes each sensor against a ball rolled dead-center (per-sensor
`CENTER_READING`, measured with a centering jig) — this absorbs each sensor's fixed
mounting/optical bias. Set these constants at the top of
`microcontroller/putt_tracker/putt_tracker.ino` and re-flash, or use the app's
in-gate calibration. Re-measure if you ever change the mounting.

## 7. Set up the app and Firebase

Putts are stored in **your own** Firebase project — there's no shared backend. Follow
[`SETUP.md`](SETUP.md) to create the Firebase project (Auth + Firestore + rules),
then build and run the **iOS app** on a real device (BLE doesn't work in the
Simulator). Optionally run the **web app** to browse your history in a browser.

## 8. Roll your first putt

1. Power the gate from the USB-C bank; it advertises over BLE as **`PuttingGate`**.
2. Open the iOS app, sign in, and let it connect to the gate on the **Gate** tab.
3. Roll a putt through the gate. The ESP32 measures the offset on-device and sends
   it over BLE; the app records it to Firestore and the laser flashes to confirm.
4. Check the **History** tab (or the web app) to see the putt, its push/pull offset
   in mm, and speed.

That's a working gate. From here, build up sessions per putter, distance, and break
to see your tendencies over time.

---

For how the whole system fits together, see [`README.md`](README.md); for running
the software on your own infrastructure, [`SETUP.md`](SETUP.md).

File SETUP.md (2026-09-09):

# Setting up your own Open Putt

This guide walks you through running Open Putt on **your own infrastructure** —
your own Firebase project, your own iOS build, your own hardware gate. The repo
ships no shared backend; everything is scoped to a Firebase project *you* create,
so your putts live in your database and nobody else's.

If you just want to understand what the pieces are, read the top-level
[`README.md`](README.md) first. This document is the practical "clone → run" path.

## What you'll stand up

```
Hardware gate (ESP32) ─BLE→ iOS app ──(Firebase iOS SDK)──┐
Web app ──────────────────(Firebase Web SDK)──────────────┼─→ YOUR Firestore
   └─ Firebase Auth (email/password)                       │   ▲ firestore.rules
                                                            │
(optional) ESP32 direct-post → Cloud Run: FastAPI ─────────┘
```

The **only required cloud service is a Firebase project** (Auth + Firestore). The
FastAPI backend is optional — it exists only for an ESP32 that posts putts
directly over WiFi, which the reference hardware does *not* do (it uses BLE to the
phone). You can ignore the whole `backend/` directory unless you specifically want
that path.

## Prerequisites

| For | You need |
|-----|---|
| Everything | A Google account and the [Firebase CLI](https://firebase.google.com/docs/cli) (`npm i -g firebase-tools`), Node.js 20+ |
| Web app | The above |
| iOS app | A Mac with Xcode 15+, and an Apple ID (a free one is fine for running on your own device) |
| Hardware | An ESP32 dev board, 3× VL53L4CD ToF sensors, a laser module, and [`arduino-cli`](https://arduino.github.io/arduino-cli/) — parts in [`PARTS_LIST.md`](PARTS_LIST.md), wiring in [`microcontroller/README.md`](microcontroller/README.md) |
| Backend (optional) | A billing-enabled Google Cloud project and the `gcloud` CLI |

---

## 1. Create your Firebase project

1. Go to the [Firebase console](https://console.firebase.google.com/) and **create a
   project**. Note its **Project ID** (e.g. `my-putting-gate`) — you'll use it
   everywhere below.
2. **Enable Authentication → Sign-in method → Email/Password.** The apps gate all
   data behind a signed-in user; email/password is the only provider wired up.
3. **Create a Firestore database** (Build → Firestore Database → Create database) in
   **Native mode**. Pick a region close to you.
4. From the repo root, point the Firebase CLI at your project and deploy the
   security rules and indexes:

   ```bash
   firebase login
   firebase use --add            # pick your project, alias it "default"
   firebase deploy --only firestore:rules,firestore:indexes
   ```

   `firebase use --add` writes a `.firebaserc` (gitignored). **The rules are the
   security boundary** — a signed-in user can only touch documents whose `user_id`
   is their uid. The web and iOS apps are broken/insecure until the rules are live,
   so don't skip this.

> **A note on "API keys":** The Firebase web/iOS API keys are **not secrets** — they
> identify your project to Firebase and are meant to ship in client apps. Access is
> controlled by `firestore.rules`, not by hiding the key. That's why the web config
> is fine to bake into the bundle. Real secrets (service-account keys) never belong
> in the repo; the `.gitignore` blocks the common filenames.

---

## 2. Web app (`frontend/`)

1. In the Firebase console, add a **Web app** to your project (Project settings →
   Your apps → Web). Copy the `firebaseConfig` values it shows you.
2. Create `frontend/.env.local` (gitignored) from these values:

   ```bash
   # frontend/.env.local
   VITE_FIREBASE_API_KEY=AIza...
   VITE_FIREBASE_AUTH_DOMAIN=my-putting-gate.firebaseapp.com
   VITE_FIREBASE_PROJECT_ID=my-putting-gate
   VITE_FIREBASE_APP_ID=1:1234567890:web:abcdef...
   # Optional (present in the console config; not strictly required by the app):
   VITE_FIREBASE_STORAGE_BUCKET=my-putting-gate.firebasestorage.app
   VITE_FIREBASE_MESSAGING_SENDER_ID=1234567890
   ```

3. Run it:

   ```bash
   cd frontend
   npm install
   npm run dev            # http://localhost:5173
   ```

   Create an account on the login screen (email/password) — that account owns the
   data you'll see.

4. **Deploy (optional).** To host it on Firebase Hosting:

   ```bash
   cd frontend && npm run build && cd ..
   firebase deploy --only hosting
   ```

   The repo also has a GitHub Actions workflow
   ([`.github/workflows/deploy-frontend.yml`](.github/workflows/deploy-frontend.yml))
   that auto-deploys on push to `main`. It's **fork-friendly** — nothing is
   hard-coded to a specific project, and the job skips itself until you configure
   it, so an unconfigured fork won't show failing runs. To enable it, go to
   **Settings → Secrets and variables → Actions** in your fork and set:
   - **Variables** (Repository variables): `VITE_FIREBASE_API_KEY`,
     `VITE_FIREBASE_AUTH_DOMAIN`, `VITE_FIREBASE_PROJECT_ID`,
     `VITE_FIREBASE_APP_ID`, `VITE_FIREBASE_STORAGE_BUCKET`,
     `VITE_FIREBASE_MESSAGING_SENDER_ID` — the same values as your
     `frontend/.env.local`. The workflow reuses `VITE_FIREBASE_PROJECT_ID` as the
     deploy target, so you don't set the project id twice.
   - **Secret**: `FIREBASE_SERVICE_ACCOUNT` — a service-account key JSON with
     permission to deploy Firebase Hosting (Firebase console → Project settings →
     Service accounts → Generate new private key; paste the whole JSON as the
     secret value).

   If you'd rather not use CI at all, delete the workflow and deploy manually with
   the command above.

---

## 3. iOS app (`ios/PuttingGate/`)

The iOS app is a BLE central that reads putts from the hardware gate and writes them
to your Firestore. **BLE does not work in the Simulator** — you need a real iPhone
and the physical gate to exercise the full flow, though the app builds and its
history/settings screens run in the Simulator.

1. In the Firebase console, add an **iOS app** to your project. Give it **your own
   bundle identifier** (e.g. `com.yourname.puttinggate`).
2. Download the generated **`GoogleService-Info.plist`** and save it at
   `ios/PuttingGate/GoogleService-Info.plist`. This path is **gitignored** — your
   real config never gets committed. A placeholder
   [`GoogleService-Info.plist.example`](ios/PuttingGate/GoogleService-Info.plist.example)
   shows the shape.
3. Open `ios/PuttingGate.xcodeproj` in Xcode and set **your** signing identity:
   - Target **PuttingGate** → **Signing & Capabilities** → select your **Team**.
   - Set **Bundle Identifier** to the one you registered in step 1.

   > The checked-in project file references the original author's Apple team
   > (`DEVELOPMENT_TEAM`) and bundle id (`com.puttinggate.app`). Xcode will
   > override these with your selection; just don't commit your team id back.
4. Firebase is added via Swift Package Manager and should resolve on first open
   (File → Packages → Resolve if needed). Build & run on your device.

---

## 4. Hardware gate (`microcontroller/`)

Full parts list is in [`PARTS_LIST.md`](PARTS_LIST.md); wiring, sensor geometry, the
detection math, and the BLE payload are documented in
[`microcontroller/README.md`](microcontroller/README.md).

1. Assemble the gate and wire the three ToF sensors + laser to the ESP32 per that
   README.
2. Flash the firmware (the `huge_app` partition scheme is **required** — BLE
   overflows the default):

   ```bash
   cd microcontroller/putt_tracker
   arduino-cli compile --fqbn esp32:esp32:esp32:PartitionScheme=huge_app --upload -p /dev/cu.usbserial-0001 .
   arduino-cli monitor -p /dev/cu.usbserial-0001 -c baudrate=115200
   ```

3. The gate advertises over BLE as **`PuttingGate`**. The service/characteristic
   UUIDs in the firmware must match the iOS app (`GateConnection.swift`) — they do
   out of the box; only change them if you change both sides.

The reference firmware has **no WiFi and no device token** — it talks only BLE to
the phone, so there's nothing secret to configure on the device.

---

## 5. Backend on Cloud Run (optional — skip unless you need it)

You only need this if you want an ESP32 that posts putts **directly** over WiFi
(bypassing the phone), or you otherwise want the FastAPI ingest service. The
reference setup does **not** use it.

The deploy script [`backend/deploy/cloud-run.sh`](backend/deploy/cloud-run.sh) is
parameterized by environment variables — you don't edit the file. Only `PROJECT`
(your Google Cloud project id) is required; `REGION`, `AR_REPO`, `SERVICE`,
`SA_NAME`, and `CORS_ORIGIN` have sensible defaults (`CORS_ORIGIN` defaults to your
project's Firebase Hosting domain, `https://<PROJECT>.web.app`):

```bash
# after `gcloud auth login`, against a billing-enabled project
PROJECT=my-gcp-project bash backend/deploy/cloud-run.sh
# override a default if you need to:
PROJECT=my-gcp-project REGION=europe-west1 bash backend/deploy/cloud-run.sh
```

Before running, put `DEVICE_INGEST_TOKEN` and `DEVICE_INGEST_UID` in `backend/.env`
(the script seeds them into Secret Manager). Use `--fast` for a code-only
rebuild+redeploy.

The service authenticates the ESP32 with a shared token you set as secrets
(`DEVICE_INGEST_TOKEN` / `DEVICE_INGEST_UID`). The runtime service account gets
Firestore access via Application Default Credentials — no key file needed. See the
comments in the deploy script and [`CLAUDE.md`](CLAUDE.md) for the details.

To run the backend locally against the Firestore emulator, use `./start.sh` from the
repo root (it launches the emulator, the backend on `:8000`, and the web app on
`:5173`, attributing all data to a single dev user).

---

## Local development with the emulator

`./start.sh` runs the whole web stack locally with the **Firestore emulator**, so you
can develop without touching real Firestore:

```bash
./start.sh
```

It needs the Firebase CLI and a Java runtime for the emulator. It sets
`AUTH_DEV_UID=local-dev` (skips token verification and attributes all data to one dev
user), so you don't even need a real login for local web work. If `firebase` isn't
installed it warns and runs without persistence.

---

## Checklist

- [ ] Firebase project created; Email/Password auth enabled; Firestore (Native) created
- [ ] `firebase deploy --only firestore:rules,firestore:indexes` run
- [ ] `frontend/.env.local` filled from your Web app config; `npm run dev` works
- [ ] iOS app added in Firebase; `GoogleService-Info.plist` dropped in; your Team + bundle id set in Xcode
- [ ] Firmware flashed with `huge_app`; gate advertises as `PuttingGate`
- [ ] (optional) backend deploy script edited to your project and deployed

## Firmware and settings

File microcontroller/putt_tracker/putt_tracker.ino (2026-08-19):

// Putt offline-detector for ESP32.
//   Laser  red (+) -> GPIO26, black (-) -> GND
//   Mux    SDA -> GPIO21, SCL -> GPIO22, VIN -> 3V3, GND -> GND
//   3x VL53L4CD on mux channels 0, 7, 4 (Sensor 1, 2, 3)
// Turns the laser on, calibrates the empty gate, then reports each putt's offset
// from center as PUSH (past center) / PULL (short of center) and sends it over
// BLE to the phone app, which relays it to the backend under the user's login.

#include <Wire.h>
#include <math.h>
#include <vl53l4cd_class.h>
#include <BLEDevice.h>
#include <BLEServer.h>
#include <BLEUtils.h>
#include <BLE2902.h>

// ---------- Tuning constants (ported from putt_tracker.py) ----------
#define MUX_ADDR 0x70
const uint8_t CHANNELS[3] = {0, 7, 4};        // Sensor 1, 2, 3
const int     N = 3;

const int      LASER_PIN        = 26;
const int      LASER_FLASH_COUNT = 3;         // blinks that confirm a captured putt
const uint32_t LASER_FLASH_MS    = 120;       // on/off half-period of each blink
// Per-sensor raw reading (mm) with a ball rolled dead-center through the gate,
// measured with the centering jig. The offset is the deviation from this, so a
// center hit reads ~0 and each sensor's fixed bias — mounting differences and the
// middle sensor's crosstalk offset — is absorbed. Re-measure if the mount changes.
// Order matches CHANNELS {ch0, ch7, ch4} = Sensor 1, 2, 3.
const float    CENTER_READING[N] = {72.2, 77.2, 70.0};
const float    DETECT_MARGIN_MM = 25.0;       // drop below baseline = ball present
const float    DEAD_BAND_MM     = 2.0;        // |offset| within this -> CENTER
const uint32_t CLEAR_TIMEOUT_MS = 150;        // gate clear this long -> finalize
const int      CALIB_SAMPLES    = 20;         // empty-gate reads per sensor at startup
const bool     INVERT_PUSH_PULL = false;      // flip if labels come out backwards
const float    GAP_MM_FALLBACK  = 178.0;      // used only if a sensor won't calibrate
// Center-to-center distance between adjacent in-line sensors (along the roll
// direction). Speed = distance travelled / time between sensor crossings.
// MEASURE THIS on your mount — an inaccurate value scales every speed linearly.
// Assumes the three sensors are evenly spaced (Sensor 1 -> 2 -> 3).
const float    SENSOR_SPACING_MM = 33.32;

VL53L4CD sensor0(&Wire, -1);
VL53L4CD sensor1(&Wire, -1);
VL53L4CD sensor2(&Wire, -1);
VL53L4CD *sensors[3] = {&sensor0, &sensor1, &sensor2};

float baseline[N];
float threshold[N];

// detection state
bool     eventActive = false;
uint32_t lastSeen    = 0;
float    minReading[N];       // -1 = sensor hasn't seen the ball this event
uint32_t minReadingTime[N];   // millis() at each sensor's closest approach (for speed)
float    maxReading[N];       // farthest ball-present reading this event (diagnostic)
int      sampleCount[N];      // how many ball-present samples this sensor took (diagnostic)
const int MAX_SAMPLES = 128;  // cap on stored per-sensor samples per putt (diagnostic)
float    samples[N][MAX_SAMPLES];  // raw ball-present readings, in capture order
int      puttNum     = 0;

// One session per boot; every putt this power-cycle is grouped under it.
String   sessionId;

// ---------- BLE (putts are sent to the phone app, which relays them) ----------
// Custom 128-bit UUIDs; must match the iOS app (GateConnection).
#define SERVICE_UUID        "6b1a0001-8c2f-4d3a-9e5b-1f2c3d4e5f60"
#define CHARACTERISTIC_UUID "6b1a0002-8c2f-4d3a-9e5b-1f2c3d4e5f60"

BLECharacteristic *puttChar = nullptr;
bool centralConnected = false;   // a phone is connected (and can receive notifies)

// Track connect/disconnect so we only flash the laser when a phone is listening,
// and re-advertise after a disconnect so it can reconnect.
class ServerCallbacks : public BLEServerCallbacks {
  void onConnect(BLEServer *s) override {
    centralConnected = true;
    Serial.println("BLE: phone connected");
  }
  void onDisconnect(BLEServer *s) override {
    centralConnected = false;
    Serial.println("BLE: phone disconnected, re-advertising");
    BLEDevice::startAdvertising();
  }
};

void muxSelect(uint8_t ch) {
  Wire.beginTransmission(MUX_ADDR);
  Wire.write(1 << ch);
  Wire.endTransmission();
}

// --- Reading-quality gate (rejects sun / IR-flooded samples) ---------------
// The VL53L4CD ranges with a 940 nm IR laser, and sunlight is very bright at
// 940 nm. When the gate's far wall is lit by the sun it reflects that IR back
// into the sensors, which can still return range_status 0 but with a distance
// biased *short* — reading the empty wall as ~120 mm instead of ~175 mm. That
// trips the ball-present threshold and produces phantom putts (observed
// outdoors as a consistent +48..+60 mm PUSH). These gates drop such samples so
// they never look like a ball. Both fields are already in real units (the ULD
// converts them): sigma_mm is the sensor's own std-dev estimate of the distance
// in mm; a trustworthy target reads a few mm, sun blows it up. The signal:ambient
// test requires the target return to stand clearly above the ambient IR floor —
// it self-scales, so it stays lax indoors (near-zero ambient) and tightens in
// sun. Tune from the serial log with GATE_QUALITY_DEBUG set to 1.
#define GATE_QUALITY_DEBUG 0
const float SIGMA_MAX_MM       = 15.0;   // reject a reading noisier than this
const float MIN_SIGNAL_AMBIENT = 1.5;    // signal_rate must be >= this x ambient_rate

// Distance in mm for sensor i (channel must already be selected).
// Returns -1 if there's no fresh reading, the sensor flags it invalid, or it
// fails the sun/IR quality gate above.
float readSensorMM(int i) {
  uint8_t ready = 0;
  sensors[i]->VL53L4CD_CheckForDataReady(&ready);
  if (!ready) return -1;
  sensors[i]->VL53L4CD_ClearInterrupt();
  VL53L4CD_Result_t res;
  sensors[i]->VL53L4CD_GetResult(&res);
  if (res.range_status != 0) return -1;       // 0 = valid target
  // Quality gate: drop noisy / IR-flooded samples that pass range_status but
  // aren't trustworthy (see the note above).
  if (res.sigma_mm > SIGMA_MAX_MM ||
      (float)res.signal_rate_kcps < MIN_SIGNAL_AMBIENT * (float)res.ambient_rate_kcps) {
#if GATE_QUALITY_DEBUG
    Serial.print("  ch"); Serial.print(CHANNELS[i]);
    Serial.print(" reject: d=");    Serial.print(res.distance_mm);
    Serial.print(" sigma=");        Serial.print(res.sigma_mm);
    Serial.print(" signal=");       Serial.print(res.signal_rate_kcps);
    Serial.print(" ambient=");      Serial.println(res.ambient_rate_kcps);
#endif
    return -1;
  }
  return (float)res.distance_mm;
}

float medianOf(float *a, int n) {
  for (int i = 1; i < n; i++) {                // insertion sort
    float key = a[i];
    int j = i - 1;
    while (j >= 0 && a[j] > key) { a[j + 1] = a[j]; j--; }
    a[j + 1] = key;
  }
  return a[n / 2];
}

void calibrate() {
  Serial.println("Calibrating empty gate - keep the bridge clear...");
  for (int i = 0; i < N; i++) {
    float samples[CALIB_SAMPLES];
    int got = 0;
    uint32_t start = millis();
    while (got < CALIB_SAMPLES && millis() - start < 3000) {
      muxSelect(CHANNELS[i]);
      float d = readSensorMM(i);
      if (d > 0) samples[got++] = d;
    }
    if (got == 0) {
      baseline[i] = GAP_MM_FALLBACK;
      Serial.print("  ch"); Serial.print(CHANNELS[i]);
      Serial.print(": no reading, using "); Serial.println(GAP_MM_FALLBACK, 0);
    } else {
      baseline[i] = medianOf(samples, got);
      Serial.print("  ch"); Serial.print(CHANNELS[i]);
      Serial.print(": baseline "); Serial.print(baseline[i], 1); Serial.println(" mm");
    }
    threshold[i] = baseline[i] - DETECT_MARGIN_MM;
  }
}

void classify(float offset, const char **label, float *mag) {
  float o = INVERT_PUSH_PULL ? -offset : offset;
  if (o > DEAD_BAND_MM)       { *label = "PUSH";   *mag = o; }
  else if (o < -DEAD_BAND_MM) { *label = "PULL";   *mag = -o; }
  else                        { *label = "CENTER"; *mag = fabs(o); }
}

// Closest-approach distance for sensor i, ignoring the first and last samples.
// Those are the ball caught off-axis at the edge of the ~18° cone, so they read
// long; the true perpendicular distance is the lowest of the middle samples.
// Falls back to the overall min when there are too few samples to trim safely.
float closestMiddle(int i) {
  int n = sampleCount[i];
  if (n < 3 || n > MAX_SAMPLES) return minReading[i];
  float m = samples[i][1];
  for (int k = 2; k < n - 1; k++) if (samples[i][k] < m) m = samples[i][k];
  return m;
}

void report() {
  // Only count a putt when every sensor saw the ball. A real putt rolls over all
  // three in-line sensors in sequence; a partial detection (some sensor never
  // saw it) is almost always an errant read — e.g. sunlight tripping a single
  // sensor outdoors — so ignore it entirely: no putt number, no BLE notify, no
  // laser flash.
  int detected = 0;
  for (int i = 0; i < N; i++) if (minReading[i] >= 0) detected++;
  if (detected < N) {
    Serial.print("Ignoring partial detection (");
    Serial.print(detected); Serial.print("/"); Serial.print(N);
    Serial.println(" sensors) - not counted as a putt.");
    return;
  }

  puttNum++;
  Serial.print("\n--- Putt #"); Serial.print(puttNum); Serial.println(" ---");
  float sum = 0;
  float sumReading = 0;
  int count = 0;
  for (int i = 0; i < N; i++) {
    Serial.print("  Sensor "); Serial.print(i + 1);
    Serial.print(" (ch"); Serial.print(CHANNELS[i]); Serial.print("): ");
    if (minReading[i] < 0) {
      Serial.println("no detection");
      continue;
    }
    float closest = closestMiddle(i);   // lowest of the middle samples (drop first/last)
    float offset = closest - CENTER_READING[i];   // deviation from this sensor's center
    const char *label;
    float mag;
    classify(offset, &label, &mag);
    sum += offset;
    sumReading += closest;
    count++;
    // Full spread for diagnosis, then the value actually used (trimmed closest
    // approach) and the offset it maps to.
    Serial.print("min "); Serial.print(minReading[i], 1);
    Serial.print(" / max "); Serial.print(maxReading[i], 1);
    Serial.print(" mm ("); Serial.print(sampleCount[i]); Serial.print(" samples), used ");
    Serial.print(closest, 1); Serial.print(" mm  ->  ");
    Serial.print(offset >= 0 ? "+" : "-");
    Serial.print(mag, 1); Serial.print(" mm  "); Serial.println(label);

    // Full per-sample trace of the pass (capture order), for diagnosis.
    Serial.print("      samples: ");
    int shown = sampleCount[i] < MAX_SAMPLES ? sampleCount[i] : MAX_SAMPLES;
    for (int k = 0; k < shown; k++) {
      if (k) Serial.print(' ');
      Serial.print(samples[i][k], 0);
    }
    if (sampleCount[i] > MAX_SAMPLES) Serial.print(" ...(capped)");
    Serial.println();
  }
  if (count > 0) {
    float avg = sum / count;
    const char *label;
    float mag;
    classify(avg, &label, &mag);
    Serial.print("  Avg reading:    ");
    Serial.print(sumReading / count, 1); Serial.println(" mm");
    Serial.print("  Avg offset:     ");
    Serial.print(avg >= 0 ? "+" : "-");
    Serial.print(mag, 1); Serial.print(" mm  "); Serial.println(label);

    // Speed: the ball crosses the in-line sensors in sequence, so the separation
    // between the first and last sensor it tripped, over the time between those
    // crossings, is its speed. mm/ms == m/s, so no unit conversion is needed.
    // Needs the ball to trip >= 2 sensors; otherwise it's not measurable (null).
    float speed_mps = -1.0;
    int firstIdx = -1, lastIdx = -1;
    for (int i = 0; i < N; i++) {
      if (minReading[i] < 0) continue;
      if (firstIdx < 0) firstIdx = i;
      lastIdx = i;
    }
    if (firstIdx >= 0 && lastIdx > firstIdx) {
      uint32_t t0 = minReadingTime[firstIdx], t1 = minReadingTime[lastIdx];
      uint32_t dt = (t1 >= t0) ? (t1 - t0) : (t0 - t1);
      if (dt > 0) {
        speed_mps = (SENSOR_SPACING_MM * (lastIdx - firstIdx)) / (float)dt;
        Serial.print("  Speed:          ");
        Serial.print(speed_mps, 2); Serial.println(" m/s");
      }
    }

    // Build the putt payload and send it to the phone over BLE. Per-sensor
    // entries are the signed offset (or null where that sensor didn't see the
    // ball); speed_mps is null when the ball tripped fewer than two sensors.
    // The phone relays this JSON verbatim to POST /api/device/putts.
    String json = "{";
    json += "\"session_id\":\"" + sessionId + "\",";
    json += "\"putt_index\":" + String(puttNum) + ",";
    json += "\"offset_mm\":" + String(avg, 1) + ",";
    json += "\"label\":\"" + String(label) + "\",";
    json += "\"speed_mps\":" + (speed_mps >= 0 ? String(speed_mps, 2) : String("null")) + ",";
    json += "\"sensors\":[";
    for (int i = 0; i < N; i++) {
      if (i) json += ",";
      json += (minReading[i] < 0)
        ? "null"
        : String(closestMiddle(i) - CENTER_READING[i], 1);
    }
    json += "]}";
    if (notifyPutt(json)) flashLaser();   // confirm only when a phone received it
  }
}

void resetEvent() {
  eventActive = false;
  for (int i = 0; i < N; i++) {
    minReading[i] = -1;
    maxReading[i] = -1;
    sampleCount[i] = 0;
  }
}

// Blink the gate laser a few times to confirm a putt was received by the phone,
// then leave it on (it's the aiming reference for the next putt). Detection uses
// the ToF sensors, not the laser, so blinking it doesn't affect measurement.
void flashLaser() {
  for (int i = 0; i < LASER_FLASH_COUNT; i++) {
    digitalWrite(LASER_PIN, LOW);
    delay(LASER_FLASH_MS);
    digitalWrite(LASER_PIN, HIGH);
    delay(LASER_FLASH_MS);
  }
}

// A canonical UUID (8-4-4-4-12 hex) for this session. The backend stores it as
// sessions.id (a uuid column), so it must be UUID-shaped. Randomness comes from
// esp_random() (hardware RNG, seeded once the BLE radio is up).
String makeSessionId() {
  uint8_t b[16];
  for (int i = 0; i < 16; i += 4) {
    uint32_t r = esp_random();
    b[i] = r; b[i + 1] = r >> 8; b[i + 2] = r >> 16; b[i + 3] = r >> 24;
  }
  b[6] = (b[6] & 0x0F) | 0x40;   // version 4
  b[8] = (b[8] & 0x3F) | 0x80;   // variant 1
  char buf[37];
  snprintf(buf, sizeof(buf),
           "%02x%02x%02x%02x-%02x%02x-%02x%02x-%02x%02x-%02x%02x%02x%02x%02x%02x",
           b[0], b[1], b[2], b[3], b[4], b[5], b[6], b[7],
           b[8], b[9], b[10], b[11], b[12], b[13], b[14], b[15]);
  return String(buf);
}

// Bring up the BLE peripheral: one service with a notify characteristic that
// carries each putt's JSON. Advertises as "PuttingGate" so the phone app can
// find and connect to it.
void startBLE() {
  BLEDevice::init("PuttingGate");
  BLEServer *server = BLEDevice::createServer();
  server->setCallbacks(new ServerCallbacks());
  BLEService *service = server->createService(SERVICE_UUID);
  puttChar = service->createCharacteristic(
    CHARACTERISTIC_UUID, BLECharacteristic::PROPERTY_NOTIFY);
  puttChar->addDescriptor(new BLE2902());   // lets the phone subscribe to notifies
  service->start();

  BLEAdvertising *adv = BLEDevice::getAdvertising();
  // The 128-bit service UUID (16 bytes) and the "PuttingGate" name together
  // overflow the 31-byte advertising packet, which would silently drop the UUID
  // and make iOS's UUID-filtered scan miss the gate. Put the UUID in the primary
  // advertisement and the name in the scan response so both fit.
  BLEAdvertisementData advData;
  advData.setFlags(0x06);   // LE General Discoverable + BR/EDR not supported
  advData.setCompleteServices(BLEUUID(SERVICE_UUID));
  BLEAdvertisementData scanResp;
  scanResp.setName("PuttingGate");
  adv->setAdvertisementData(advData);
  adv->setScanResponseData(scanResp);
  BLEDevice::startAdvertising();
  Serial.println("BLE: advertising as 'PuttingGate'");
}

// Send one putt's JSON to the connected phone as a BLE notification. Returns
// false (no-op) when no phone is connected — detection keeps running either way.
bool notifyPutt(const String &json) {
  if (!centralConnected || puttChar == nullptr) return false;
  puttChar->setValue((uint8_t *)json.c_str(), json.length());
  puttChar->notify();
  Serial.println("BLE: putt sent");
  return true;
}

void setup() {
  // Laser ON first, as always.
  pinMode(LASER_PIN, OUTPUT);
  digitalWrite(LASER_PIN, HIGH);

  Serial.begin(115200);
  delay(500);
  Serial.println("Laser ON.");

  Wire.begin(21, 22);            // SDA=GPIO21, SCL=GPIO22
  Wire.setClock(400000);

  Serial.println("Initializing sensors...");
  for (int i = 0; i < N; i++) {
    muxSelect(CHANNELS[i]);
    sensors[i]->begin();
    if (sensors[i]->InitSensor() != 0) {
      Serial.print("  ch"); Serial.print(CHANNELS[i]); Serial.println(": INIT FAILED");
      continue;
    }
    sensors[i]->VL53L4CD_SetRangeTiming(10, 0);   // 10 ms budget, continuous
    sensors[i]->VL53L4CD_StartRanging();
    Serial.print("  ch"); Serial.print(CHANNELS[i]); Serial.println(": OK");
  }

  startBLE();
  sessionId = makeSessionId();
  Serial.print("Session: "); Serial.println(sessionId);

  resetEvent();
  calibrate();
  Serial.println("\nReady - roll a putt through the gate.");
}

void loop() {
  uint32_t now = millis();
  for (int i = 0; i < N; i++) {
    muxSelect(CHANNELS[i]);
    float d = readSensorMM(i);
    if (d > 0 && d < threshold[i]) {              // ball in this beam
      eventActive = true;
      lastSeen = now;
      if (sampleCount[i] < MAX_SAMPLES) samples[i][sampleCount[i]] = d;  // keep the trace
      sampleCount[i]++;
      if (d > maxReading[i]) maxReading[i] = d;       // spread of ball-present samples
      if (minReading[i] < 0 || d < minReading[i]) {  // closest approach
        minReading[i] = d;
        minReadingTime[i] = now;                     // when the ball was nearest this sensor
      }
    }
  }
  if (eventActive && (now - lastSeen) > CLEAR_TIMEOUT_MS) {
    report();         // print + BLE notify; flashes the laser if a phone received it
    resetEvent();
  }
}

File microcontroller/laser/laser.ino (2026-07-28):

// Laser test — drives the laser on GPIO26.
//   Laser red (+)  -> GPIO26
//   Laser black (-) -> GND
// Blinks 2s on / 2s off to confirm GPIO26 is under program control.
// (In the final putt tracker the laser just stays on.)

const int LASER_PIN = 26;

void setup() {
  pinMode(LASER_PIN, OUTPUT);
  digitalWrite(LASER_PIN, LOW);   // start off
  Serial.begin(115200);
  Serial.println("Laser test starting on GPIO26");
}

void loop() {
  digitalWrite(LASER_PIN, HIGH);
  Serial.println("Laser ON");
  delay(2000);
  digitalWrite(LASER_PIN, LOW);
  Serial.println("Laser OFF");
  delay(2000);
}

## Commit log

2026-06-26 Fix golf ball detection: adaptive radius and relaxed ROI
    The hardcoded minRadius=60 was larger than the actual ball radius
    (~45px for a typical portrait phone video), causing HoughCircles to
    miss the ball entirely and latch onto spurious circles in the background.
    - Compute min/max radius from frame width (w//50 and w//12) so detection
    scales correctly regardless of video resolution or shooting distance
    - Remove the y1=h//3 vertical cutoff for first-frame detection so the
    ball can be found anywhere in the frame, not just the bottom two-thirds
    - Add a full-frame fallback pass if the ROI-constrained search returns
    nothing, preventing a miscalibrated ROI from causing total failure
    Co-Au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
2026-06-26 Track ball with CSRT instead of per-10th-frame Hough re-detection
    Uses cv2.TrackerCSRT to follow the ball frame-by-frame once an initial
    Hough detection locks on. Hough runs every 5 frames only when the tracker
    is absent (initial acquisition or after loss). Downward-movement validation
    discards positions that drift upward beyond one ball radius, resetting the
    tracker if needed. Swaps opencv-python-headless for opencv-contrib-python-headless
    since CSRT ships in the contrib package.
2026-06-26 Seed CSRT tracker from initial ball position detected at upload time
    The pre-detected ball position (x, y) from /detect-ball was never forwarded
    to /analyze, so the tracker had to wait for Hough to find the ball during
    analysis — often latching onto the wrong object. Now ball_x_hint and
    ball_y_hint are passed through and used to initialize the CSRT tracker
    on frame 0, ensuring tracking starts from the correct position immediately.
2026-06-26 Correct CSRT drift with periodic Hough re-anchoring every 10 frames
    A rolling golf ball rotates as it travels, causing the CSRT appearance
    model to chase the rotating texture and drift off-center. Every 10 frames,
    Hough circle detection now runs in a tight ROI around the current tracked
    position. If it finds the ball within 2x ball_r, the tracker is
    re-initialized at the Hough-detected center, snapping back to the true
    ball center before drift accumulates.
2026-06-27 Add frame-by-frame video viewer with Plyr
    Replace the native <video controls> with the Plyr player and custom
    frame-stepping controls (prev/next buttons, frame counter, FPS field).
    Frame rate is auto-detected via requestVideoFrameCallback with a manual
    override; left/right arrow keys step one frame. The calibration canvas is
    re-parented into Plyr's video wrapper so the overlay stays aligned.
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2026-06-29 Detect mount laser dots to anchor ball tracking and auto-calibrate
    The white ball was hard to find against busy carpet, so Hough circles
    kept latching onto furniture and the putter hosel. The camera mount now
    projects two red laser dots — top marks the ball's rest position, bottom
    marks the target — which are the only saturated-red points in the scene
    and trivial to segment by color.
    - analyzer: add _detect_laser_dots (red-dominance mask + connected
    components) and _nearest_circle. detect_ball_in_frame anchors the ball
    search to a tight box around the top laser and picks the nearest circle,
    returning the laser points plus derived gate_center_x / gate_line_y.
    analyze_putt seeds t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
2026-06-29 Draw the aim line through both laser dots and anchor the gate on the target
    The "center" line was a fixed vertical through the frame middle and the gate
    took its x from the top laser. Now the aim line follows the real putt line and
    the gate sits on the target.
    - analyzer: detect_ball_in_frame derives gate_center_x/gate_line_y from the
    bottom dot (the target) instead of the top dot; ball search still anchors on
    the top dot where the ball rests.
    - App.tsx: drawCalibration draws the green aim line through both laser dots
    (extended to the frame edges) with the label following it, falling back to the
    vertical line at cx when no lasers are found. The gate ticks and target line
    already k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
2026-06-30 Find the ball by inscribed-circle distance transform, reject the putter
    Real-green testing showed the previous colour-blob detector failed at address:
    the metallic shaft fuses to the ball in the white mask, so a contour-shape test
    (circularity/solidity) rejected the merged blob and lost the ball entirely,
    leaving a garbage Hough fallback. Colour alone can't separate a matte-white ball
    from polished metal.
    - _white_ball_candidates now takes the peak of each connected component's
    distance transform: the centre of the largest inscribed circle, radius = peak.
    A thin shaft contributes only small distances, so this locks onto the round
    ball and ignores attachments even when they touch it.
    -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
2026-06-30 Anchor the gate on the bottom laser dot even when it's the only one
    _detect_laser_dots returns dots sorted top-to-bottom, and the gate was anchored
    on lasers[1] — so when only one dot was detected (the target on the green, which
    is the large, reliable dot; the upper ball-rest dot is small and often missing)
    it landed in lasers[0], was treated as the "top" reference, and the gate was left
    unset. Anchor the gate on the bottom-most dot (lasers[-1]) regardless of count,
    and only use a dot as the ball-rest reference when a second, higher dot exists.
    Verified across 12 real clips: the gate now lands on the target dot in every
    case, including the four where only that single dot is detected.
    Co-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
2026-06-30 Measure offset perpendicular to the aim line, not vertically
    The offset was the horizontal distance from the ball's gate-line crossing to the
    bottom dot's x. With a tilted mount the aim line (ball-rest dot → target dot) is
    not vertical, so this axis disagreed with the drawn aim line. Now the gate is the
    line through the target perpendicular to the aim line, and offset is the signed
    perpendicular distance from that line — correct under any mount rotation.
    - _crossing_x -> _aim_crossing: interpolates where the track reaches the target
    along the aim direction and returns the signed perpendicular offset.
    - analyze_putt takes aim_top_x/aim_top_y (the top laser dot); falls back to the
    bal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
2026-06-30 Stabilize ball center with a distance-weighted core centroid
    On fast clips the ball's alignment line and motion blur split the white mask
    into lobes, and the distance-transform peak (single largest inscribed circle)
    flipped between them frame to frame — e.g. IMG_0012 jumped x=524->589 across two
    consecutive near-gate frames, inflating the crossing offset.
    Keep the distance transform for sizing and the radius gate (still rejects the
    thin shaft), but take the centre as the distance-weighted centroid of the
    component core (dist > half the peak). Averaging the thick core across both lobes
    removes the flip; the thin shaft and blur fringe fall below the threshold and are
    excluded, so the addres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
2026-07-01 Add putt speed at the gate to the analysis
    Report the ball's speed (m/s) as it crosses the gate, where the
    gate-width calibration is exactly valid. analyze_putt now resolves an
    effective FPS (frontend-measured, then container, then 30) and records
    each detected position's frame index, so speed uses real elapsed time
    even when the tracker drops a frame. The gate-straddling segment found
    by _aim_crossing sizes the displacement for the new _gate_speed_mps
    helper. The frontend sends its measured fps and shows the speed beside
    the offset.
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2026-07-02 Slim the iOS app to a record-and-upload client
    Move all putt analysis to the backend. The app now only records a video
    (manual start/stop) and uploads it; on-device motion and ball detection
    are removed.
    - Delete MotionDetector, BallDetector, RingBuffer, ClipWriter, and the
    motion-triggered CaptureService; replace with CameraRecorder wrapping
    AVCaptureMovieFileOutput.
    - Collapse the Session/Clip model to a single Recording; rewire the
    coordinator, upload service, and app entry point accordingly.
    - Reduce the UI to a Record button, a flat recordings history with upload
    status/retry, and Settings limited to backend URL + resolution.
    Note: the SwiftData schema change (Session/Clip ->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
2026-07-02 Lower the camera exposure for outdoor recording
    Bias auto-exposure -2 EV (clamped to the device range) so bright outdoor
    light doesn't overexpose the white ball and green.
2026-07-02 Persist analyzed putting sessions to Supabase Postgres
    Add a sessions/putts schema (Supabase migration) storing the iOS Recording
    metadata alongside the backend session-analysis result and flattened
    calibration. The /analyze-session endpoint now accepts the optional iOS
    metadata fields and upserts the session plus its putts via a service-role
    Supabase client; persistence fails soft when unconfigured and never breaks
    the analysis response. Point the iOS uploadPath at /analyze-session.
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2026-07-03 Return human-readable analysis errors and surface them on iOS
    Map calibration failures to one actionable message (e.g. missing gate
    lasers or ball at address) instead of a per-frame technical dump, make
    the video open/read errors plain-language, and return a clear 422 when
    calibration succeeds but no valid putt is found. The raw per-frame
    detail is still logged server-side.
    On iOS, accumulate the upload response body and parse FastAPI's detail
    so a failed upload shows the server's message rather than a bare status
    code; HistoryView already displays it.
2026-07-03 Keep the event loop free and stream large uploads
    Offload the blocking, decode-bound analysis (analyze_putt,
    analyze_session, detect_ball_in_frame) and the Supabase persist call to
    a threadpool so uvicorn can still answer health checks during a long
    analysis — the synchronous work was blocking the single event loop and
    tripping Fly's port health check into 502s.
    Stream uploads to a temp file in 1 MiB chunks instead of reading the
    whole file into memory, so 200 MB+ session clips no longer risk OOM on
    the receive path.
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2026-07-04 Upload videos directly to Cloud Storage via signed URLs
    Cloud Run caps request bodies at 32 MiB, so routing the video through
    /analyze-session failed (413) for real clips. Instead, POST /uploads now
    mints a short-lived V4 signed URL (IAM signBlob — no key file) and the
    client PUTs the video straight to GCS. /analyze-session becomes a JSON
    call that verifies the object exists, creates the queued session row, and
    enqueues the Cloud Task. No video passes through Cloud Run.
    Frontend and iOS both switch to the get-URL -> PUT-to-GCS -> start flow;
    iOS keeps the background URLSession for the PUT (relaunch-safe via
    taskDescription) and points at the Cloud Run URL. The deploy script adds
    bucket CO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
2026-07-04 Calibrate from the bottom dot and ball for the 0.5x lens
    The ultra-wide (0.5x) lens makes the laser dots small and dim, so the
    strict red-dot thresholds found nothing ("couldn't find the laser gate").
    Loosen the detector (redness>35 & r>140, min area 4) and change the model
    to use only the bottom dot as the gate anchor, with the aim line running
    from the ball at address through that dot — the ball replaces the old top
    dot (too faint at 0.5x). The offset math already supported a ball-based
    aim near-point.
2026-07-04 Add a local mode to run the whole flow without GCP
    LOCAL_MODE=1 swaps Cloud Storage for a local directory (served via new
    PUT/GET /local-storage endpoints) and Cloud Tasks for an in-process job,
    so the exact upload -> analyze -> playback flow works on a laptop against
    only hosted Supabase. Storage calls are now mode-aware and the process
    logic is factored into _process_session, shared by the Cloud Tasks
    handler and the local job. start.sh exports LOCAL_MODE=1. Production is
    unchanged: with GCP configured it uses GCS + Cloud Tasks as before.
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2026-07-06 Add Capture test pre-flight and 120fps recording
    Record at 120fps when the lens supports it (best-effort, falls back to the
    preset default without switching lenses so the 0.5x calibration holds).
    Add a "Capture test" that sends one live frame to a new POST /calibration-check
    endpoint and reports whether the laser gate and ball at address are visible,
    so a scene can be fixed before recording an unanalyzable putt. The check
    reuses detect_ball_in_frame and shares its guidance wording.
2026-07-06 Speed up backend deploys with smaller context and cached builds
    Add backend/.gcloudignore so `gcloud run deploy --source`/`builds submit`
    stops uploading .venv (~220MB) and tests/fixtures (~535MB) each deploy.
    Add a cached Cloud Build (BuildKit --cache-from + inline cache) so code-only
    rebuilds reuse the ffmpeg/pip layers, and wire cloud-run.sh to build by image
    with a --fast flag that skips provisioning for code-only redeploys.
2026-07-07 Add putt-type filters (length + break slope) to sessions list
    Add two filter dropdowns to the dashboard sessions list: putt length in
    three-foot increments and break slope (left to right / right to left /
    straight). Length buckets are derived from the sessions present so only
    populated ranges are offered, and a Clear button resets both filters.
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2026-07-09 Retain session videos regardless of analysis outcome
    Previously a recorded clip was only copied to the retained sessions/
    prefix when analysis succeeded; calibration errors, no-putt clips, and
    unexpected failures deleted the transient upload. Now every terminal
    outcome retains the video and records its path on the session row, so no
    recording a player captured is lost to a failed analysis.
    - main.py: extract a _retain_video helper; _record_error now retains the
    clip (recording video_path) before dropping the uploads/ copy, and the
    enqueue-failure path routes through it too
    - db.py: set_session_status accepts an optional video_path so an errored
    session still links to its retained clip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
2026-07-10 Fix horizontal scroll on mobile; make layout fully responsive
    Prevent unwanted horizontal page scroll on iOS Safari:
    - Add text-size-adjust: 100% so iOS doesn't auto-inflate fonts (a common
    cause of overflow that doesn't reproduce in desktop browsers), plus an
    overflow-x guard and overflow-wrap on the root elements.
    - Make the large .offset-value metric fluid (clamp) so big numbers fit on
    one line on narrow phones instead of wrapping/overflowing.
    - Let the putts table scroll within its own card (overflow-x-auto) instead
    of being clipped by overflow-hidden on small screens.
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2026-07-13 Rename Putters.tsx to PuttersPage.tsx to fix case-insensitive collision
    The component file Putters.tsx and data-layer file putters.ts differ only
    in case, which collides on case-insensitive filesystems (macOS). This made
    `import Putters from "./Putters"` resolve to putters.ts (no default export)
    instead of the component, breaking local dev.
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2026-07-13 Migrate iOS auth to Firebase SDK; wire Cloud SQL deploy + cutover runbook
    iOS:
    - AuthManager rewritten on FirebaseAuth (same public API: state, userID,
    validAccessToken, signIn/signUp/signOut) + resetPassword; FirebaseApp.configure
    at launch; LoginView gains a Forgot password action.
    - Remove the hand-rolled GoTrue REST auth (AuthService, KeychainStore,
    SupabaseConfig) and trim AuthModels to AuthUser.
    - Manual Xcode steps (add FirebaseAuth SPM package, add GoogleService-Info.plist)
    documented in the runbook.
    Infra:
    - cloud-run.sh: connect to Cloud SQL over the mounted socket (cloudsql.client,
    --add-cloudsql-instances, DB_* env + DB_PASSWORD secret, FIREBASE_PROJECT_ID);
    drop the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
2026-07-14 Fix calibration/pre-flight mismatch on underexposed videos
    The capture-test pre-flight used detect_ball_in_frame (which has a Hough
    edge fallback) while real auto-calibration used colour segmentation only,
    so a dark clip could pass the pre-flight yet fail analysis with the
    misleading "Couldn't find the ball at address" error — the fallback had
    latched onto a phantom bright circle, not the ball.
    - Add shared _detect_scene helper (colour segmentation, no Hough) used by
    both _calibrate and check_calibration_frame, so a passing pre-flight now
    genuinely predicts a successful recording.
    - Detect underexposure (_is_underexposed / DARK_MEAN_V) and surface a
    "too dark — add light" message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
2026-07-14 Add on-demand session re-analysis
    Let users re-run analysis on a session's already-uploaded video from the
    web app, without a re-upload — e.g. to pick up an analyzer improvement.
    - db.begin_reanalysis: reset an owned session to 'queued', clear its prior
    putts, and return the retained video path, stored fps, and metadata to
    re-run with (preserving the user's distance/break edits).
    - POST /sessions/{id}/reanalyze: reprocess the retained sessions/ clip
    through the same pipeline. An `already_retained` flag threads through
    _process_session/_record_error/_run_local_job/process so the clip — the
    only copy — is left in place rather than re-copied and deleted.
    - Frontend: reanalyzeSe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
2026-07-14 Add client-side routing to the frontend
    Replace the hand-rolled useState view switching in App.tsx with
    react-router-dom. Each screen now has its own URL (/, /analyze,
    /sessions/:id, /putters), enabling deep links, bookmarks, and browser
    back/forward. Page components keep their callback-prop APIs, wired to
    navigate() at the App layer so they stay decoupled from the router.
    Firebase Hosting already has the SPA catch-all rewrite, so clean-path
    routing works in production.
    Claude-Session: https://claude.ai/code/session_01F1beW9zE7Ls1dWmV9o7ke8
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2026-07-14 Fix datetime serialization crash when re-analyzing in production
    begin_reanalysis returned captured_at as a raw datetime from the DB, and that
    metadata dict is json.dumps'd into the Cloud Tasks payload, raising
    "Object of type datetime is not JSON serializable" and 503-ing the reanalyze
    endpoint. Local mode dodged it by running the job in-process. Hand captured_at
    back as an ISO string (matching the upload path, where it arrives as a string);
    persist_session re-inserts it into the timestamptz column unchanged.
2026-07-15 iOS: auto-calibrate before recording, and pick the putter
    Two record-screen changes that share RecordView.
    Auto-calibration — the capture test was a one-shot button that was easy to
    skip, so people recorded clips that couldn't be analyzed. Run it continuously
    instead:
    - CaptureTestModel gains a Task-driven loop (startAuto/stopAuto) that checks
    every 10s and stops once a check passes, so it doesn't hammer
    /calibration-check. Re-armed on record-end, foreground, tab re-entry, or a tap
    on the card. Retries fast while the camera warms up (no frame yet), keeps the
    last verdict visible while refreshing, and ignores transient network blips.
    - RecordView drops the manual button, shows the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
2026-07-28 Fix device putt direction inversion; persist per-sensor offsets
    Direction fix: the shared frontend applies a face-on camera mirror
    (golferSide negates offset_mm), but the hardware gate isn't a camera, so a
    PUSH was displaying as "left". Pre-invert offset_mm (and the per-sensor
    values) at /api/device/putts so a PUSH reads as "right" and matches the
    stored direction.
    Per-sensor offsets: new putts.sensor_offsets_mm jsonb column (migration
    0006 + schema.sql) records the three ToF readings behind each putt's
    average. Carried through ingest_device_putt, returned in _PUTT_COLS, and
    typed on the frontend PuttRow. Null for video-pipeline putts.
    Also commits the CENTER_MM -> 89 mm correction (measur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
    [putt_tracker.ino]
2026-07-28 Show per-sensor offsets in the session putt table
    Add a "Sensors (mm)" column to SessionDetail's putt table, rendered only
    when the session has per-sensor data (the hardware gate), so video sessions
    are unchanged. Values are shown in the golfer's frame (same face-on mirror
    undo as the Offset/Direction columns); a sensor that didn't see the ball
    shows an em dash. Lets you compare the three sensors' agreement per putt.
2026-07-29 Per-sensor center calibration; trim off-axis edge samples
    Replace the shared (reading + radius - CENTER_MM) offset model with a
    per-sensor CENTER_READING[]: each sensor's raw reading for a ball rolled
    dead-center through the gate (measured with a centering jig). Offset is the
    deviation from that, so a center hit reads ~0 and each sensor's fixed bias —
    mounting differences plus the middle sensor's optical crosstalk — is
    absorbed in one step. Seeded from jig data {72.2, 77.2, 70.0}.
    Also: closestMiddle() drops the first/last samples (the ball caught
    off-axis at the edge of the ~18 deg cone, which read long) and uses the
    lowest of the middle samples. Diagnostic output now prints min/max/sa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
    [putt_tracker.ino]
2026-07-29 Connect the iOS app to the ESP32 gate over BLE
    Replace the ESP32's direct WiFi POST with a BLE link: the gate advertises
    as "PuttingGate" and notifies each putt's JSON; the iOS app connects as a
    BLE central, shows putts live, and relays each to POST /api/device/putts
    under the signed-in user's Firebase login (no hotspot, correct attribution).
    Firmware: drop WiFi/HTTP, add a BLE peripheral (notify characteristic).
    Advertise the 128-bit service UUID in the primary packet and the name in
    the scan response so both fit the 31-byte advert (else iOS can't find it).
    Flash the laser on phone-received. Needs the huge_app partition (BLE).
    Backend: require_user_or_device — /device/putts now accepts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
    [putt_tracker.ino]
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2026-07-31 Only count a putt when every sensor detected the ball
    Outdoors, the gate produced errant reads — sunlight tripping a single sensor
    registered as a putt. A real putt rolls over all three in-line sensors in
    sequence, so require a complete set of sensor readings and ignore any partial
    detection.
    Enforced at every trust boundary:
    - Firmware (putt_tracker.ino): report() drops an event unless all N sensors saw
    the ball — no putt number, no BLE notify, no laser flash.
    - iOS (GatePutt/GateConnection): a putt with any missing per-sensor value is
    ignored — not shown, not relayed, not treated as a session's first putt.
    - Backend (POST /device/putts): rejects (422) a putt whose sensors are mi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
    [putt_tracker.ino]
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2026-08-19 Microcontroller: reject sun/IR-flooded ToF samples
    Outdoors with the gate's far wall in direct sun, the VL53L4CD sensors
    (940 nm) get flooded with reflected IR and return range_status 0 but a
    distance biased short — reading the empty wall as ~120 mm instead of
    ~175 mm. That trips the ball-present threshold and produces phantom putts
    (seen as a consistent +48..+60 mm PUSH).
    Add a quality gate in readSensorMM(): drop a sample when its sigma_mm
    exceeds a cap or its signal rate isn't clearly above the ambient IR
    floor. The signal:ambient test self-scales, so it stays lax indoors and
    tightens in sun. Both thresholds are tunable constants; GATE_QUALITY_DEBUG
    prints rejected samples for field tu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
    [putt_tracker.ino]
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
